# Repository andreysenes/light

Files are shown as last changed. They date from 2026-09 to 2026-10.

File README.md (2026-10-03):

# StageMod v0 — Iluminação de palco modular + MIDI

Repositório GitHub: [github.com/andreysenes/light](https://github.com/andreysenes/light) — ver [docs/GITHUB.md](docs/GITHUB.md) para `git push`.

**4 módulos** acopláveis (**8× WS2812B** cada, 32 pixels na cadeia) + **tubo 4 m** (200 LEDs), controlados pela **Medusa** (**Pro Micro** + **ZS-040** Bluetooth) ou **USB**, a partir de uma DAW.

## Arquitetura v0

```
DAW ──BT──► [ZS-040]──► [Pro Micro] ──D6──► Mod1 ──► Mod2 ──► Mod3 ──► Mod4
     └──USB (opc.)──────►      └── D5 ──► tubo neon 4 m
                               Fonte 5V 10A (C14 na Medusa)
```

| Peça | Função |
|---|---|
| **Medusa** | Pro Micro + **ZS-040** + fonte + XLR |
| **ZS-040** | MIDI sem fio (Bluetooth → Serial1) — [19-ZS-040.md](docs/19-ZS-040.md) |
| **Módulo spot** | 1× WS2812B + pass-through 5V/GND/DATA |
| **Tubo flex** | Fita WS2812B em tubo silicone — gradiente / chase (pin D5) |
| **Fonte 5V** | Pro Micro + spots + tubo (≥ **3A** com tubo) |

Cada WS2812B = **RGB completo** (milhões de cores via MIDI).

## Começar

| Passo | Onde |
|---|---|
| 1. Montar e soldar | [docs/22-MANUAL-MONTAGEM.md](docs/22-MANUAL-MONTAGEM.md) (sem caps/resistores) |
| 2. Upload firmware | [firmware/promicro-4mod/](firmware/promicro-4mod/) |
| 3. Mapear MIDI no DAW | [docs/05-MIDI-DAW.md](docs/05-MIDI-DAW.md) |
| 4. Controlar pelo browser | [andreysenes.github.io/light](https://andreysenes.github.io/light/) |

## Documentação v0

| Documento | Conteúdo |
|---|---|
| [Visão geral](docs/00-VISAO-GERAL.md) | Objetivos e decisões v0 |
| [Arquitetura](docs/01-ARQUITETURA-MODULAR.md) | Cabeça + 4 módulos em cadeia |
| [LEDs](docs/02-LEDS-E-OPTICA.md) | WS2812B RGB |
| [Eletrônica](docs/03-ELETRONICA.md) | Pro Micro, data, 5V |
| [Alimentação](docs/04-ALIMENTACAO.md) | Fonte 5V, limites |
| [MIDI / DAW](docs/05-MIDI-DAW.md) | CC RGB, notas, presets |
| [BOM](docs/06-BOM.md) | Lista de materiais v0 |
| [Cablagem](docs/07-CABLAGEM.md) | Fios por módulo |
| [XLR](docs/16-XLR-CONECTORES.md) | Pinagem 3 pinos — tubo + módulos |
| [**Cabeça Medusa**](docs/17-CABECA-MEDUSA.md) | Caixa Pro Micro + saídas XLR |
| [ZS-040](docs/19-ZS-040.md) | Bluetooth na Medusa |
| [MIDI sem fio](docs/18-WIRELESS-MIDI.md) | DAW, latência, bridge PC |
| [**Tubo flex**](docs/14-TUBO-FLEX.md) | Gradiente, chase, MIDI CC 15–19 |
| [**Compras AliExpress**](docs/15-ALIEXPRESS-BOM.md) | **O que buscar e o que evitar** |
| [Inventário hardware](docs/20-INVENTARIO-HARDWARE.md) | **O que já temos** |
| [**Lista de compras**](docs/21-LISTA-COMPRAS-RESTANTE.md) | **Itens restantes** |
| [**Manual de montagem**](docs/22-MANUAL-MONTAGEM.md) | Soldagem e ordem de montagem |
| [**Módulo spot 3D**](docs/23-MODULO-SPOT-3D.md) | STL + impressão + montagem mecânica |
| [Roadmap](docs/08-ROADMAP.md) | v0 atual → v1 futuro |
| [Resumo rápido](docs/DECISAO-RESUMO.md) | Decisões em 2 minutos |

## Decisões v0

| Tópico | Decisão |
|---|---|
| Cabeça | **1× Pro Micro** (ATmega32U4, MIDI USB) |
| Módulos | **4×** com **1 WS2812B** cada |
| Cor | **RGB completo** por módulo (CC 1–14) |
| Alimentação | **5 V** / ≥ 1 A |
| Dados spot | **D6** — cadeia 4 módulos |
| Tubo flex | **D5** — fita WS2812B (efeitos gradiente) |
| Cabos | 5V + GND + DATA (fios ou **XLR 3 pinos**) |

## MIDI rápido

| Módulo | R | G | B |
|---|---|---|---|
| 1 | CC 1 | CC 2 | CC 3 |
| 2 | CC 4 | CC 5 | CC 6 |
| 3 | CC 9 | CC 10 | CC 11 |
| 4 | CC 12 | CC 13 | CC 14 |

Notas **C3–F3** = módulos 1–4 (velocity = brilho). **CC 7** = dimmer. **PC 0** = blackout.

## v1 (futuro)

Rig de palco 24V, LEDs 10W, ESP32, P4 + RJ45 — especificação em [docs/v1/](docs/v1/).

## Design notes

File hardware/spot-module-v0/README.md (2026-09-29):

# Módulo spot StageMod v0 — impressão 3D

Coluna em **U** com **difusor frontal recuado** e **tampa inferior** para dois XLR (IN fêmea / OUT macho), alinhado ao visual de referência do projeto.

## Arquivos

| Arquivo | Descrição |
|---|---|
| `stagemod_spot_v0.scad` | Modelo paramétrico (OpenSCAD) |
| `stl/spot_body.stl` | Corpo (U + pés + calço LED) |
| `stl/spot_diffuser.stl` | Painel difusor |
| `stl/spot_bottom_plate.stl` | Tampa inferior (XLR) |
| `stl/spot_led_clip.stl` | Clipe opcional para fita |

Documentação de montagem elétrica: [docs/22-MANUAL-MONTAGEM.md](../../docs/22-MANUAL-MONTAGEM.md).  
Guia completo CAD: [docs/23-MODULO-SPOT-3D.md](../../docs/23-MODULO-SPOT-3D.md).

## Regenerar STL

```bash
./export-stl.sh
```

Requer [OpenSCAD](https://openscad.org/) 2021+.

## Ajuste rápido

No topo de `stagemod_spot_v0.scad`:

- `led_pitch` / `led_count` — deve bater com o seu PCB de 8× WS2812B  
- `xlr_hole_d` — medir o furo do conector XLR painel que você comprou  
- `outer_w`, `total_h` — escala estética

## Impressão sugerida

| Peça | Material | Notas |
|---|---|---|
| Corpo + tampa | PETG ou ABS | 0,2 mm, 3 perímetros, 20% infill |
| Difusor | PETG branco natural ou PLA branco | 0,12–0,2 mm; 2–4 perímetros; **100% infill** ou 4–6 paredes para difundir |
| Clipe | PETG | Opcional |

Orientação: corpo **deitado** (frente para cima ou costas na mesa) para boa resistência dos pés.

## Montagem (resumo)

1. Soldar LEDs e XLR conforme manual (sem caps/resistores).  
2. Encaixar PCB no calço interno; fios pela canaleta até a tampa.  
3. Parafusar XLR na `bottom_plate`; parafusar tampa no corpo (M3 × 10).  
4. Encaixar difusor na frente; 4× M3 × 8 (laterais do painel, opcional os da coluna lateral).  
5. Etiquetar **MOD 1…4**.

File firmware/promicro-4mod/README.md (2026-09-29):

# StageMod v0 — Firmware Pro Micro + 4× WS2812B

Firmware oficial da **v0**: **1 Pro Micro** e **4 LEDs WS2812B** (um por módulo), **RGB completo** via MIDI.

Documentação: [docs/](../../docs/) · MIDI: [05-MIDI-DAW.md](../../docs/05-MIDI-DAW.md) · Cablagem: [07-CABLAGEM.md](../../docs/07-CABLAGEM.md) · Cabeça: [17-CABECA-MEDUSA.md](../../docs/17-CABECA-MEDUSA.md)

## O que este firmware faz

- **MIDI USB** (cabeça perto do PC) + **Serial1** ← **ZS-040** (palco) — [18-WIRELESS-MIDI.md](../../docs/18-WIRELESS-MIDI.md)
- **4 módulos lógicos** = **32 pixels** (8 WS2812B por módulo físico, mesma cor por CC)
- **RGB completo** em cada módulo — qualquer cor via CC
- **Tubo flexível** (pin D5) — gradiente, chase, rainbow ([14-TUBO-FLEX.md](../../docs/14-TUBO-FLEX.md))
- Notas **C3–F3** acendem o módulo com a cor RGB já definida; **velocity** = brilho
- **PC 0–6** = presets de cor (blackout, warm, R, G, B, magenta, branco)
- **CC 7** = master dimmer

## Ligação elétrica

### Visão geral

```
[Fonte 5V] ──┬── VCC Pro Micro
             ├── VCC Mód 1 ── VCC Mód 2 ── VCC Mód 3 ── VCC Mód 4
             └── GND comum (Pro Micro + todos os módulos)

Pro Micro D6 ──► [470Ω] ──► DIN Mód1 ── ... ──► Mód4
Pro Micro D5 ──► [470Ω] ──► DIN fita WS2812B no tubo flexível
```

### Por módulo (chicote simples)

| Fio | IN | No módulo | OUT |
|-----|-----|---|-----|
| Vermelho | 5V | → LED VCC | 5V pass-through |
| Preto | GND | → LED GND | GND pass-through |
| Branco/verde | DATA | → LED DIN | LED DOUT → próximo |

Cada módulo é só **1 WS2812B** + 3 fios de pass-through (energia) + data série.

### Pro Micro (5V, 16MHz)

| Pro Micro | Liga em |
|---|---|
| **VCC** | 5V da fonte (ou USB só para programar — **não** alimentar 4 LEDs só no USB) |
| **GND** | GND comum |
| **D6** (ou `LED_PIN` no .ino) | Resistor 470Ω → DIN do módulo 1 |
| **RAW** | Opcional: 5V da fonte se não usar VCC |

### Boas práticas WS2812B

- **Cada módulo:** resistor **470 Ω** (DATA IN → DIN) + cap **470–1000 µF** (5V/GND no LED)
- **Medusa:** **470 Ω** em D5/D6 antes do XLR + **1000 µF** no barramento 5 V
- Fonte **5V / mín. 1 A** (4 LEDs × ~60 mA ≈ 240 mA no pior caso; use 1–2 A)
- Cabo de dados curto no protótipo (< 30 cm entre módulos)

## Arduino IDE — instalação

1. Placa: **Arduino Leonardo** ou **SparkFun Pro Micro** (5V, 16MHz)
2. Bibliotecas:
   - `MIDI Library` (FortySevenEffects)
   - `FastLED`
3. Abrir `promicro-4mod.ino` → Upload
4. No DAW: habilitar dispositivo MIDI USB do Pro Micro

### Pro Micro — pinagem comum

| Função | Pin |
|---|-----|
| LED data (padrão) | **6** |
| Alternativa | 5, 7, 8, 9… (alterar `LED_PIN`) |

## Mapa MIDI — RGB por módulo

Cada módulo tem **3 CCs** (R, G, B). Valor 0–127 no DAW → 0–255 no LED.

| Módulo | Vermelho | Verde | Azul |
|---|---|---|---|
| **1** | CC **1** | CC **2** | CC **3** |
| **2** | CC **4** | CC **5** | CC **6** |
| **3** | CC **9** | CC **10** | CC **11** |
| **4** | CC **12** | CC **13** | CC **14** |

| Entrada | Ação |
|---|---|
| **CC 1–14** | Define cor RGB do módulo (efeito imediato) |
| Nota **60–63** (C3–F3) | Módulo 1–4 — acende com cor dos CCs; velocity = brilho |
| Nota off | Apaga o módulo |
| **CC 7** | Master dimmer (todos) |
| **PC 0** | Blackout |
| **PC 1** | Warm white (todos) |
| **PC 2** | Vermelho |
| **PC 3** | Verde |
| **PC 4** | Azul |
| **PC 5** | Magenta |
| **PC 6** | Branco |

### Exemplo no DAW

1. Enviar **CC 1 = 127, CC 2 = 0, CC 3 = 0** → módulo 1 fica vermelho.
2. **CC 2 = 127** → amarelo (R+G).
3. Nota **C3** com velocity 100 → módulo 1 com brilho ~80 %.

Qualquer combinação R+G+B = **milhões de cores** — é a vantagem do WS2812B.

## Teste sem DAW

Após upload, o boot pisca os 4 módulos em branco em sequência. Se não piscar:

1. Verificar ordem GRB no `COLOR_ORDER` (alguns clones usam RGB)
2. Trocar `LED_PIN`
3. Medir 5V no LED

## Próximo passo (firmware)

- [x] RGB completo por módulo (CC 1–14)
- [ ] Migrar Cabeça para ESP32-S3 + RS-485 (doc principal do repo)
- [ ] Trocar WS2812B por LEDs 10W quando hardware estiver pronto

## v1 (futuro)

Rig 24V / 10W / ESP32 — [docs/v1/](../../docs/v1/README.md). A v0 valida **MIDI → luz modular** antes dessa migração.

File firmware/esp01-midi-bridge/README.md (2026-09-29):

# ESP-01 — bridge MIDI UDP → serial (opcional)

**Não faz parte da Medusa v0** — a cabeça usa **ZS-040** ([19-ZS-040.md](../../docs/19-ZS-040.md)). Este sketch é alternativa Wi‑Fi para quem não usar Bluetooth.

## Hardware

| ESP-01 | Ligação |
|---|---|
| VCC | **3,3 V** (regulador na Medusa) |
| GND | GND comum |
| TX | Pro Micro **RX (D0 / Serial1)** |
| RX | Pro Micro **TX (D1)** via divisor 5V→3,3 V |

**CH_PD** (EN) no ESP-01: ligar a **3,3 V** para manter o chip ativo.

## Upload

1. Adaptador USB **3,3 V** para ESP-01 (GPIO0 → GND no flash).
2. Arduino IDE: placa **Generic ESP8266 Module**, 1 MB flash.
3. Editar `WIFI_SSID` / `WIFI_PASS` no `.ino`.
4. Upload; anotar IP (Serial Monitor após boot ou roteador).

## Protocolo

- **UDP** porta **5004**
- Payload = bytes MIDI (ex. `0xB0 0x01 0x7F` = CC1 no canal 1)
- Sem cabeçalho extra — repasse direto para UART

## PC

Ver script de exemplo em [docs/18-WIRELESS-MIDI.md](../../docs/18-WIRELESS-MIDI.md).

## Pro Micro

`ENABLE_SERIAL_MIDI 1` e `SERIAL_MIDI_BAUD 115200` em `promicro-4mod.ino`.

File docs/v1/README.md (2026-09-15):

# StageMod v1 — planejado (não implementado)

Especificação do rig de palco **futuro**: ESP32-S3, módulos **2× 10 W**, alimentação **24 V**, cabos **P4 + RJ45**, lentes **20 mm 90°**.

O projeto **atual** é a **v0** (Pro Micro + 4× WS2812B) — ver [README principal](../../README.md).

| Documento | Conteúdo |
|---|---|
| [Cablagem P4 + RJ45](09-CABLAGEM.md) | Energia e dados separados |
| [Módulo Dual 10W](10-MODULO-DUAL.md) | WW + vermelho, ATtiny |
| [Configuração módulos](11-CONFIGURACAO-MODULOS.md) | `modules.json`, combinações de cor |
| [Lente 20 mm](12-LENTE-20MM.md) | Óptica 90° |
| [modules.json.example](modules.json.example) | Config v1 |

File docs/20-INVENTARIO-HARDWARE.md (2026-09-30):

# Inventário — hardware em mãos (Andrey)

Estado do rig **v0** com o que já está comprado/montado.

## Já temos

| Item | Especificação | Firmware / notas |
|---|---|---|
| **Pro Micro** | 5 V, ATmega32U4 | Cabeça Medusa |
| **ZS-040** | BLE → Serial1 | [19-ZS-040.md](19-ZS-040.md) |
| **Fonte** | **5 V 10 A** | Dentro da Medusa + **C14** |
| **Módulos spot** | **4×** WS2812B, **8 LEDs** cada | **32 pixels** na cadeia D6 — MIDI ainda **4 módulos** lógicos (CC 1–14) |
| **Tubo** | **4 m** × **50 LED/m** = **200 LEDs** | D5, WS2811 — `NUM_TUBE_LEDS 200` |

### Cadeia de pixels (pin D6)

```
Medusa D6 ──► [Mod1: LED 0–7] ──► [Mod2: 8–15] ──► [Mod3: 16–23] ──► [Mod4: 24–31]
```

Cada módulo físico: **8 LEDs** em série internos; **DOUT** do módulo → **DIN** do próximo. No firmware, **um** CC RGB acende **os 8 LEDs** do módulo com a mesma cor.

### Tubo (pin D5)

| Campo | Valor |
|---|---|
| Comprimento | 4 m |
| Densidade | 50 LED/m |
| Total | **200** addressable |
| Chip | WS2811 (D15-Woven Magic) |

## Ainda falta

Lista de compras completa: **[21-LISTA-COMPRAS-RESTANTE.md](21-LISTA-COMPRAS-RESTANTE.md)**.

Resumo: caixa Medusa + **C14** + fusível + XLR (Medusa e módulos) + cabos + USB painel.  
**Montagem/soldagem:** [22-MANUAL-MONTAGEM.md](22-MANUAL-MONTAGEM.md).

## Corrente (referência)

| Carga | Nominal / pico |
|---|---|
| 32 LEDs módulos (branco full) | ~**2 A** |
| Tubo 200 LED (manual 3,1 W/m) | ~**2,5 A** nominal |
| Pro Micro + ZS-040 | ~**0,15 A** |
| **Fonte 10 A** | Folga para efeitos e pico no tubo |

Injeção **5 V** no **meio** do tubo 4 m continua recomendada.

## Checklist primeiro power-on

1. [ ] `LEDS_PER_MODULE 8` e `NUM_TUBE_LEDS 200` no `.ino` (já padrão no repo)
2. [ ] Ligação 5V/GND/DATA conforme [22-MANUAL-MONTAGEM.md](22-MANUAL-MONTAGEM.md)
3. [ ] Ordem cadeia: Mod1 (C3) → Mod2 → Mod3 → Mod4 (F3)
4. [ ] Boot: cada módulo pisca **8 LEDs** juntos R/G/B/W; depois teste tubo
5. [ ] ZS-040 @ 115200 ou USB para MIDI

## Referências

- [07-CABLAGEM.md](07-CABLAGEM.md)
- [17-CABECA-MEDUSA.md](17-CABECA-MEDUSA.md)
- [firmware/promicro-4mod/](../firmware/promicro-4mod/)

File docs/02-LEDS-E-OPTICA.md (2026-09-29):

# LEDs — WS2812B RGB (v0)

## LED usado

| Item | Especificação |
|---|---|
| Tipo | **WS2812B** (ou WS2812B-B breakout) |
| Tensão | **5 V** |
| Cor | **RGB completo** — 8 bits por canal |
| Por módulo físico | **8× WS2812B** (mesma cor via MIDI) |
| Módulos lógicos (MIDI) | **4** |
| Total cadeia D6 | **32 pixels** |
| Tubo D5 | **200** LEDs (4 m × 50/m) |

## Por que WS2812B na v0

| Vantagem | Detalhe |
|---|---|
| RGB completo | Milhões de cores — sem misturar LEDs mono |
| 1 fio data | Cadeia simples entre módulos |
| Barato | Comum em estoque DIY |
| Integrado | Driver dentro do LED — sem MOSFET |

## Cor e brilho

| Controle MIDI | Efeito |
|---|---|
| CC 1–14 | R, G, B por módulo (0–255) |
| CC 7 | Master dimmer (FastLED brightness) |
| Velocity (notas) | Escala RGB do módulo |
| PC presets | Cores pré-definidas em todos |

Não é necessário LED warm white separado — **R+G parcial** faz amarelo/laranja; **R+G+B** faz branco.

## Consumo

| Estado | Corrente por LED | 4 LEDs |
|---|---|---|
| Apagado | ~1 mA | ~4 mA |
| Cor média | ~20–40 mA | ~80–160 mA |
| Branco full | ~60 mA | **~2 A** (32 LEDs) + tubo à parte |

Fonte **5V / 1A** é suficiente com margem.

## Ordem de cores no firmware

```cpp
#define COLOR_ORDER GRB   // padrão WS2812B
```

Se as cores saírem trocadas (vermelho aparece verde), testar `RGB` ou `BGR` no `.ino`.

## Limitações vs. palco grande

| WS2812B v0 | LED 10W v1 (futuro) |
|---|---|
| ~0,3 W / LED | ~10–20 W / módulo |
| Luz de proximidade / efeito | Wash de palco |
| Sem lente dedicada | Lente 20mm 90° planejada |

Para wash de palco grande, evoluir para [v1](v1/README.md).

## Boot visual

Após upload, firmware pisca cada módulo: **vermelho → verde → azul → branco** — confirma ordem da cadeia e ordem GRB.

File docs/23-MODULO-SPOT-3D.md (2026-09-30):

# Módulo spot — design 3D (impressão + montagem)

Corpo inspirado na **coluna vertical** de referência: perfil em **U**, **difusor branco recuado** na frente, **pés** nas laterais e **parafusos aparentes** (M3) na lateral e na base do difusor.

| Item | Valor padrão (CAD) |
|---|---|
| Altura total | **300 mm** |
| Largura frontal | **48 mm** |
| Profundidade | **34 mm** |
| LEDs | **8× WS2812B** em coluna (pitch **10 mm** ajustável no `.scad`) |
| Conectores | **2× XLR** na tampa inferior (IN ≈ 25% largura, OUT ≈ 75%) |

Arquivos: [`hardware/spot-module-v0/`](../hardware/spot-module-v0/).

---

## Peças impressas (×4 módulos)

| STL | Qtd/módulo | Função |
|-----|---|---|
| `spot_body.stl` | 1 | Carcaça U + pés + calço para PCB |
| `spot_diffuser.stl` | 1 | Painel difusor frontal |
| `spot_bottom_plate.stl` | 1 | Base com furos XLR |
| `spot_led_clip.stl` | 0–2 | Opcional se a fita não encaixar no calço |

Hardware de montagem (por módulo, típico):

| Item | Qtd |
|---|-----|
| Parafuso M3 × 10 | 4 (tampa) + 2–4 (difusor) |
| Porca M3 ou insert térmico M3 | conforme furo |
| XLR fêmea painel (IN) | 1 |
| XLR macho painel (OUT) | 1 |

---

## Fluxo de montagem mecânica

```
1. Imprimir corpo + difusor + tampa
2. Soldar 8 LEDs + fios nos XLR (ver manual elétrico)
3. Parafusar XLR na tampa inferior; passar cabos pelo furo central
4. Fixar tampa no corpo (M3 nos 4 cantos)
5. Encaixar PCB no calço traseiro; fios pela canaleta
6. Deslizar difusor no slot frontal; parafusar na base (e opcionalmente lateral)
7. Etiqueta MOD 1…4 na parte de trás
```

Ordem elétrica e testes: [22-MANUAL-MONTAGEM.md](22-MANUAL-MONTAGEM.md) — Parte 3 (cabos) e Parte 5 (firmware).

---

## Ajustar ao seu LED

Abra `hardware/spot-module-v0/stagemod_spot_v0.scad` e altere:

| Variável | Quando mudar |
|---|---|
| `led_pitch` | Fita 60 LED/m → ~16,7 mm; 100 LED/m → ~10 mm |
| `led_pcb_w` | Largura do breakout (muitos usam 10 mm) |
| `led_count` | Manter **8** no StageMod v0 |
| `xlr_hole_d` | Medir o recorte do conector (muitos painéis ≈ 22–24 mm) |

Depois rode `./export-stl.sh` e reimprima só a peça afetada (geralmente corpo ou difusor).

---

## Impressão 3D

| Parâmetro | Corpo / tampa | Difusor |
|---|---|---|
| Material | PETG (palco) ou PLA (prototipo) | PETG branco / PLA branco |
| Camada | 0,2 mm | 0,12–0,2 mm |
| Infill | 15–25% | 100% ou 6+ paredes |
| Suportes | Só se inclinar; preferir corpo **costas na mesa** | Não |
| Pós-processo | Lixar encaixe do difusor se apertado | Lixar faces internas para mais difusão |

**Difusor:** se a luz mostrar “pontos” dos LEDs, use filme difusor adesivo por dentro ou aumente a espessura (`diffuser_thick` no SCAD).

---

## Vista explodida (conceito)

```
        ┌─────────────┐
        │  difusor    │  ← recuado ~4,5 mm
        ├─────────────┤
        │ 8× LED      │  ← calço traseiro
        │   coluna    │
        │  (U-body)   │
        └──────┬──────┘
          pés  │  pés
        ┌──────┴──────┐
        │ bottom_plate│  ← XLR IN | XLR OUT
        └─────────────┘
```

---

## Referência visual

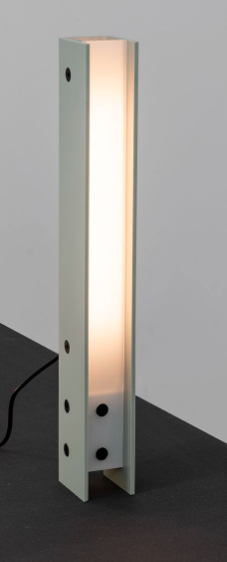
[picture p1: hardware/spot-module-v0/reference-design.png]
Referência de design


A geometria segue esta coluna (U + difusor recuado + pés). Fotos da sua montagem podem ir em `hardware/spot-module-v0/photos/`.

---

## Próximos passos (opcional)

- Versão com **encaixe magnético** na tampa para manutenção  
- **STEP** exportado do OpenSCAD para edição no FreeCAD  
- Variante **mais baixa** (~220 mm) para transporte

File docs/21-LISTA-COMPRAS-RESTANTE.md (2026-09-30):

# Lista de compras — itens restantes

**Já em mãos (não comprar de novo):** Pro Micro, ZS-040, fonte 5 V 10 A, 4 módulos WS2812B (8 LEDs cada), tubo 4 m (200 LED).

---

## Obrigatório — Medusa (cabeça)

| # | Qty | Item | Busca AliExpress / loja |
|---|-----|---|---|
| 1 | 1 | Caixa ABS grande | `ABS project box 150x100` (cabe C14 + fonte + placas) |
| 2 | 1 | **C14** painel IEC | `IEC320 C14 power inlet panel mount` |
| 3 | 1 | Cabo **C13** → tomada | `C13 power cord` (ou reaproveitar de PC) |
| 4 | 1 | Suporte fusível **5×20 mm** | `fuse holder 5x20mm panel` |
| 5 | 1 | Fusível **2 A** retardado | `5x20 fuse 2A slow blow` |
| 6 | 2 | XLR **fêmea** painel | `XLR female 3 pin panel mount` — **MOD** + **TUBO** |
| 7 | 1 | USB **micro** painel | `micro USB panel mount socket` |
| 8 | 0–1 | Par **1 kΩ + 2 kΩ** | Só se ZS-040 exigir divisor 3,3 V no RX |
| 9 | — | Fio **AWG 18** verm./preto | Barramento 5 V / GND na caixa |
| 10 | — | Fio **AWG 22** verde/branco | D5, D6 → XLR |

## Obrigatório — cada módulo spot (×4)

| # | Qty total | Item | Onde |
|---|---|---|---|
| 11 | **4** | XLR **fêmea** painel (IN) | Entrada do módulo |
| 12 | **4** | XLR **macho** painel (OUT) | Saída para o próximo módulo |

Montagem: [22-MANUAL-MONTAGEM.md](22-MANUAL-MONTAGEM.md) (ligação direta DATA/5V/GND).

## Cabos palco (tentáculos)

| # | Qty | Item | Notas |
|---|-----|---|---|
| 13 | 1 | Cabo XLR **Medusa → Mod1** | 1–2 m, 3 condutores + malha GND |
| 14 | 1 | Cabo XLR **Medusa → tubo** | 3–5 m |
| 15 | 3 | Cabo XLR **Mod → Mod** | 0,3–1 m (ou montar com `microphone cable`) |
| 16 | 0–1 | Cabo só **5 V/GND** (opc.) | Injeção no **meio** do tubo 4 m |

Montar cabo: `microphone cable 2 core shield` — vermelho=5 V, preto=GND, verde=DATA, malha=GND.

## Opcional (recomendado)

| # | Item | Motivo |
|---|---|---|
| 17 | XLR fêmea extra (**INJ**) | Só 5 V/GND para reforço no tubo |
| 18 | **AMS1117-3.3** | Só se o ZS-040 **não** aceitar 5 V no VCC |
| 19 | Chave **rocker** na entrada AC | Desligar rig sem puxar C13 |
| 20 | Terminais **spade** / olhal | C14 → fios da fonte (mais seguro que solda solta) |
| 21 | Espaçador **M3** + parafusos | Fixar Pro Micro e fonte na caixa |

---

## Checklist rápido antes de pedir

- [ ] **8×** XLR painel nos módulos (4 IN + 4 OUT) + **2×** na Medusa (MOD, TUBO)
- [ ] Caixa + C14 + fusível + USB painel
- [ ] Cabos ou material para **5** cabos XLR

## Estimativa de custo (referência)

| Grupo | ~US$ |
|---|---|
| Caixa + C14 + fusível + USB | 15–25 |
| XLR painel (10 peças) | 10–20 |
| Resistores + caps + fios | 5–10 |
| Cabos prontos (ou DIY) | 15–40 |
| **Total** | **~45–95** |

Envio Brasil: variável (Choice / Standard).

## Referências

- Montagem: [17-CABECA-MEDUSA.md](17-CABECA-MEDUSA.md)
- Inventário: [20-INVENTARIO-HARDWARE.md](20-INVENTARIO-HARDWARE.md)
- AliExpress detalhado: [15-ALIEXPRESS-BOM.md](15-ALIEXPRESS-BOM.md)

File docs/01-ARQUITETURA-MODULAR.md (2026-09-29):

# Arquitetura — v0

## Papéis

| Peça | MCU? | Função |
|---|---|---|
| **Cabeça** | Pro Micro + **ZS-040** | MIDI USB ou BT → pixels WS2812B |
| **Módulo 1–4** | Nenhum | **8× WS2812B** (1 cor MIDI) + pass-through cabos |
| **Tubo flex** | Nenhum | Fita WS2812B em tubo silicone (muitos pixels) |
| **Fonte 5V** | — | Alimentação (10A com tubo 4m) |
| **ZS-040** | BLE UART | MIDI sem fio → Serial1 — [19-ZS-040.md](19-ZS-040.md) |

Não há ESP32, RS-485 nem decoder nos módulos na v0.

## Fluxo de dados

```mermaid
flowchart LR
    DAW[DAW] -->|USB ou BT| PM[Pro Micro]
    DAW -.->|BLE| ZS[ZS-040]
    ZS -->|Serial1| PM
    PM -->|D6| M1[Módulo 1]
    M1 --> M2 --> M3 --> M4
    PM -->|D5| TUB[Tubo flex WS2812B]
```

- Cadeia D6: **32 pixels** (módulos 0–7, 8–15, 16–23, 24–31)
- MIDI: **4 módulos lógicos** — cada CC RGB pinta **8 LEDs** iguais

## Cabeça (Pro Micro)

| Item | Especificação |
|---|---|
| Placa | SparkFun Pro Micro 5V / Arduino Leonardo |
| USB | MIDI nativo (ATmega32U4) |
| Data módulos | **Pin 6** (`MODULE_PIN`) |
| Data tubo | **Pin 5** (`TUBE_PIN`) |
| Firmware | `firmware/promicro-4mod/promicro-4mod.ino` |

### Responsabilidades

1. Receber MIDI (CC, notas, Program Change)
2. Manter cor RGB de cada módulo
3. Atualizar cadeia WS2812B (`FastLED.show()`)

## Módulo (repetível × 4)

```
     IN                          OUT
  5V ──┬── VCC LED ──┬── 5V
 GND ──┴── GND LED ──┴── GND
DATA ───── DIN    DOUT ─── DATA
```

| LED na cadeia | Índice firmware | Nota MIDI |
|---|---|---|
| Módulo 1 (primeiro) | 0 | C3 (60) |
| Módulo 2 | 1 | D3 (61) |
| Módulo 3 | 2 | E3 (62) |
| Módulo 4 (último) | 3 | F3 (63) |

## Alimentação

- **5V** e **GND** em paralelo em todos os módulos (não passam pelo Pro Micro para os LEDs)
- Pro Micro: VCC da mesma fonte 5V ou USB só para programar

## Expansão

| Mudança | Esforço |
|---|---|
| Mais de 4 módulos | Alterar `NUM_MODULES` + fonte maior |
| Módulos físicos separados | Mesma cadeia DATA |
| v1 (24V, 10W) | Nova Cabeça + novos módulos — [v1/README.md](v1/README.md) |

## Topologia física

```
        [Mod1]──[Mod2]──[Mod3]──[Mod4]
           ▲
      [Cabeça Medusa: Pro Micro + XLR MOD/TUBO + fonte 5V]
```

Detalhes da caixa cabeça: [17-CABECA-MEDUSA.md](17-CABECA-MEDUSA.md).

Splits em T **não** aplicam na v0 — uma única cadeia DATA.

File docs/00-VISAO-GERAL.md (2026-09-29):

# Visão geral — StageMod v0

## Objetivo

Sistema de **4 módulos de luz** para palco/ensaio, controlados por **MIDI** a partir de uma DAW, usando componentes acessíveis:

- **Medusa**: **Pro Micro** + **ZS-040** (Bluetooth MIDI) + fonte **5V** na caixa
- **WS2812B** (RGB completo) em cada módulo
- **USB** opcional quando a cabeça está perto do PC

## O que é v0

| Inclui | Não inclui (v1) |
|---|---|
| 4 módulos, 1 LED RGB cada | LEDs 10W mono |
| MIDI USB + **ZS-040** (BT) | RS-485 / P4 / RJ45 |
| Pro Micro + ZS-040 | ESP32 |
| Cadeia WS2812B (1 fio data) | ATtiny nos módulos |
| Fonte 5V | Fonte 24V |

## Diagrama

```
┌─────────────┐   5V + GND + DATA    ┌──────────────────┐
│ Pro Micro   │ ───────────────────► │ Módulo 1         │
│ MIDI USB    │                      │ 1× WS2812B RGB   │
└─────────────┘                      └────────┬─────────┘
                                              │ DOUT
                                              ▼
                                     Mod2 ──► Mod3 ──► Mod4
```

## Módulo físico

Cada módulo é mínimo:

- **1× WS2812B** (breakout ou LED em star)
- **IN / OUT**: 5V, GND, DATA (pass-through)

Não há MCU no módulo — só o LED e fios.

## Controle de cor

O WS2812B permite **qualquer cor RGB**:

- **CC 1–14** no DAW → R, G, B de cada módulo
- **Notas C3–F3** → acendem módulo com cor definida; velocity = brilho
- **PC 0–6** → presets (blackout, warm, R, G, B, magenta, branco)

Detalhes: [05-MIDI-DAW.md](05-MIDI-DAW.md).

## Limites v0

| Fator | Valor |
|---|---|
| Módulos | **4** (fixo no firmware) |
| Corrente total | ~250 mA (4 LEDs full white) |
| Distância DATA | < 1 m entre módulos (ideal) |
| Tensão | **5 V apenas** |

## Evolução para v1

Quando o protótipo MIDI estiver validado, migrar para rig 24V / 10W / ESP32 — ver [v1/README.md](v1/README.md).

## Glossário

| Termo | Significado |
|---|---|
| Cabeça | Pro Micro — único MCU |
| Módulo | 1 WS2812B + pass-through |
| Cadeia WS2812 | LEDs em série no mesmo fio DATA |
| DIN / DOUT | Entrada / saída de dados do LED |

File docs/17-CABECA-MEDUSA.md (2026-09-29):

# Cabeça Medusa — Pro Micro + ZS-040

A **Medusa** é a caixa da cabeça do StageMod. Dentro da caixa há **apenas**:

| Peça | Função |
|---|---|
| **Pro Micro** | Pixels (D5/D6), MIDI **USB** e **Serial1** (ZS-040) |
| **ZS-040** | Bluetooth → UART → Pro Micro |
| **Entrada C14** + **fonte 5 V 10 A** (dentro da caixa) | Rede → DC para o rig |
| **Passivos / XLR** | Barramento 5 V, saídas módulos e tubo |

Não há ESP-01 nem segundo MCU — só **Pro Micro + ZS-040**.

## Dois modos de MIDI (sem trocar firmware)

| Modo | Conexão | Quando |
|---|---|---|
| **Sem fio** | DAW → BT → ZS-040 → Serial1 | Palco, cabeça longe do PC |
| **USB** | DAW → USB → Pro Micro | Cabeça perto do notebook; menor latência |

Ambos podem ficar **habilitados** no firmware; na DAW use **só um** caminho por vez.

Hardware ZS-040: [19-ZS-040.md](19-ZS-040.md) · DAW e latência: [18-WIRELESS-MIDI.md](18-WIRELESS-MIDI.md).

## Função

| Entrada | Saídas |
|---|---|
| **C14** (cabo C13 “panela”) → SMPS **5 V 10 A** interna | **MOD** — D6 + 5V + GND |
| — | **TUBO** — D5 + 5V + GND |
| — | **INJ** (opc.) — só 5V + GND |
| **DAW** (Bluetooth) | ZS-040 → Serial1 |
| **USB micro** | Pro Micro — programação + MIDI com cabo |

Pinagem XLR: [16-XLR-CONECTORES.md](16-XLR-CONECTORES.md).

## Vista geral

```
[Cabo C13 rede]──► C14 ──► [SMPS 5V 10A dentro da caixa]
                    ┌─────────────────────────────────────┐
                    │  +5V / GND barramento                 │
                    │  ┌──────────┐    ┌─────────┐        │
   [DAW BT]─────────│  │ ZS-040   │UART│Pro Micro│◄──USB (opc.)
                    │  │ (5V*)    ├───►│ Serial1 │        │
                    │  └──────────┘    └────┬────┘        │
                    │    D6 ──[470Ω]──► XLR MOD           ├──► Mod1…
                    │    D5 ──[470Ω]──► XLR TUBO          ├──► tubo
                    │    5V/GND ───────► XLR INJ          │
                    └─────────────────────────────────────┘
                    * VCC 5V se o breakout permitir; senão 3,3 V
```

```mermaid
flowchart TB
  MAINS[Rede C13/C14]
  PSU[SMPS 5V 10A interna]
  MEDUSA[Cabeça Medusa]
  BT[ZS-040 BLE]
  PM[Pro Micro]
  DAW[DAW]
  USB[USB opcional]

  MAINS --> MEDUSA
  PSU --> MEDUSA
  DAW -->|Bluetooth| BT
  BT -->|Serial1| PM
  DAW -.->|USB quando perto| PM
  PM --> MEDUSA
  MEDUSA -->|XLR MOD| CHAIN[Mod1 → Mod4]
  MEDUSA -->|XLR TUBO| TUBE[Tubo 4 m]
```

## Painel

```
┌──────────────────────────────────────────┐
│  [C14]   STAGEMOD v0      [USB micro]    │  ← C14 = entrada rede (cabo C13)
│   (MOD)  (TUBO)  (INJ)                   │
│     ○      ○       ○                     │
└──────────────────────────────────────────┘
```

Furo painel **C14** (IEC 60320): retângulo padrão do conector + 2 parafusos nas orelhas.

## Entrada de rede — conector C14

| Item | Especificação |
|---|---|
| Conector painel | **IEC C14** (receptáculo; cabo **C13** na parede) |
| Fonte interna | SMPS **100–240 V AC** → **5 V DC 10 A** (a mesma da BOM) |
| Cabo externo | **C13** macho ↔ tomada (Brasil: 127/220 V conforme rede) |

### Ligação C14 → fonte (lado AC)

Vista **traseira** do C14 (terminals em spade):

| Terminal C14 | Função | → SMPS AC |
|---|---|---|
| **Terra** (geralmente **centro** / símbolo ⏚) | PE | **FG / ⏚** da fonte |
| **Fase** | L | **L** (após **fusível** em série, ex. **2 A** retardado) |
| **Neutro** | N | **N** |

Use fio **AWG 18** (ou 1,0 mm²) para AC; **termoretrátil** e **cannotilho**; nenhum condutor exposto na tampa.

**Aviso:** trabalho em **tensão de rede** — desligar na tomada, testar com multímetro e, se não tiver experiência, pedir ajuda a eletricista. A carcaça da caixa **metálica** deve ligar ao **PE** do C14.

### Saída DC (5 V) → barramento

| SMPS DC | Medusa |
|---|---|
| **+V** | Barramento 5 V → Pro Micro, ZS-040, pinos 2 dos XLR |
| **−V** | GND comum → Pro Micro, shells XLR, INJ |

```
   [C14] ── L/N/PE ──► [Fusível] ──► SMPS 100-240V
                              │
                         +5V / GND ──┬── Pro Micro
                                      ├── ZS-040
                                      ├── [1000µF]
                                      └── XLR MOD/TUBO/INJ (pinos 1-2)
```

## Esquema elétrico interno (baixa tensão)

```
        +5V ──┬──► VCC Pro Micro
              ├──► VCC ZS-040 (5V ou 3V3 via AMS1117)
              ├──► XLR pin 2 (MOD, TUBO, INJ)
              └── [1000µF] ── GND

        GND ──┴── shells XLR, Pro Micro, SMPS −V

        ZS TX ───────────────► Pro Micro RX (D0 / Serial1)
        Pro Micro TX (D1) ───► ZS RX  (divisor se 3V3)

        D6/D5 ──[470Ω]──► XLR MOD / TUBO pin 3
```

## BOM da Medusa

| Qty | Item | Notas |
|-----|---|---|
| 1 | Pro Micro 5V 32U4 | Já tem |
| 1 | **ZS-040** (BLE UART) | Breakout com **entrada 5 V** de preferência |
| 0–1 | AMS1117-3.3 | Só se o seu ZS-040 for **3,3 V** estrito |
| 1 | **C14** painel (IEC 60320) | Entrada rede + cabo C13 |
| 1 | SMPS **5 V 10 A** 100–240 V | **Dentro** da Medusa |
| 1 | Fusível **2 A** + suporte | Série na fase (L) |
| 1 | Cabo C13 1,5 m (ou usar existente) | Tomada → Medusa |
| 1 | Caixa ABS grande | C14 + SMPS + USB + XLR |
| 2–3 | XLR fêmea painel | MOD, TUBO, INJ |
| 2 | 470 Ω | Saídas **D5** e **D6** → XLR (além do 470 Ω **em cada módulo**) |
| 1 | 1000 µF 16 V | Barramento 5 V na Medusa (além do cap **em cada módulo**) |
| 1 | USB micro painel | Pro Micro |
| — | Divisor 1k/2k | TX Pro Micro → RX ZS (se necessário) |

## Firmware

| Peça | Onde |
|---|---|
| Pro Micro | `promicro-4mod.ino` — `ENABLE_USB_MIDI 1`, `ENABLE_SERIAL_MIDI 1` |
| ZS-040 | Transparente; configurar **AT+BAUD4** (115200) uma vez |

## Ordem de montagem

1. ZS-040 em adaptador USB: testar `AT`, subir baud, parear no PC.
2. Soldar UART ao Pro Micro; upload firmware.
3. **C14 + SMPS** (AC só com caixa fechada após teste de isolamento); barramento 5 V + XLR.
4. Teste MOD com **BT** e depois com **USB**.

## Referências

- [18-WIRELESS-MIDI.md](18-WIRELESS-MIDI.md)
- [16-XLR-CONECTORES.md](16-XLR-CONECTORES.md)
- [07-CABLAGEM.md](07-CABLAGEM.md)

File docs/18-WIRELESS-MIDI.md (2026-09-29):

# MIDI sem fio — Medusa (ZS-040 + Pro Micro)

Hardware e pinagem do **ZS-040**: **[19-ZS-040.md](19-ZS-040.md)**.

Na **Medusa** o rádio é o **ZS-040** (BLE UART). O **Pro Micro** aceita **dois caminhos ao mesmo tempo**:

| Modo | Quando | Latência típica |
|---|---|---|
| **USB** no Pro Micro | Cabeça **perto** do PC (ensaio, gravação) | ~1–3 ms |
| **ZS-040** (Bluetooth) | Cabeça **no palco**, sem cabo USB | ~15–40 ms |

Para **luz com música**, **15–40 ms** costuma ser aceitável: em **120 BPM**, uma semínima ≈ **125 ms** — o atraso do BT fica **abaixo de um 16º** perceptível na maioria das cenas. Hits muito secos no beat podem preferir **USB** naquele dia.

Firmware lê **USB e Serial1 em paralelo** — não precisa recompilar ao trocar; só **não envie MIDI duplicado** da DAW para as duas portas ao mesmo tempo.

## Arquitetura

```
                    ┌─ USB MIDI (opcional, cabo curto)
DAW ──► [PC] ───────┤
        │           │
        └── BT serial ──► ZS-040 ── UART ──► Pro Micro Serial1 ──► LEDs
                              ▲
                         VCC (5V breakout comum)
```

| Camada | Função |
|---|---|
| PC | Parear BT; porta **COM** serial; bridge **MIDI → serial** (Hairless, etc.) |
| ZS-040 | BLE transparente UART |
| Pro Micro | `MIDI.read()` (USB) + `MIDI_Serial.read()` (ZS) |

## Por que ZS-040 na Medusa

| Vantagem | Detalhe |
|---|---|
| **Alimentação simples** | Muitos breakouts **ZS-040/HM-10** aceitam **5 V** no VCC (regulador onboard) — mesmo barramento da Medusa, sem ESP + AMS1117 |
| **PC** | Bluetooth nativo no notebook — sem script UDP |
| **Montagem** | UART + 4 fios; sem firmware no módulo BT |

**Alternativa** (não usada na Medusa v0): [ESP-01 + UDP](../firmware/esp01-midi-bridge/) — menor latência, mais eletrônica.

## Ligação na Medusa

### Alimentação

| Módulo | Alimentação |
|---|---|
| Pro Micro | **5 V** do barramento |
| ZS-040 | **5 V** no breakout **se** o vendedor indicar 3,3–6 V / “5V tolerant”; senão **3,3 V** do mesmo 5 V via AMS1117 |

Confirme no seu módulo: pinos **VCC / GND / TX / RX** — não inverter.

### UART (Serial1)

| Pro Micro | ZS-040 |
|---|---|
| **RX (D0)** | **TX** do módulo |
| **TX (D1)** | **RX** do módulo (divisor 5 V→3,3 V se lógica 3,3 V) |
| **GND** | **GND** |

Se o breakout já nivelar TX para o Arduino, o divisor no RX do ZS-040 pode ser opcional.

### Painel

```
[USB micro]  ← Pro Micro: programação + MIDI com cabo
[MOD][TUBO][INJ]  ← XLR
ZS-040 dentro da caixa (antena para fora do metal)
```

## Configurar baud do ZS-040

Padrão de fábrica costuma ser **9600**. Recomendado subir para **115200** (menos atraso em fila serial).

1. Ligue o ZS-040 num adaptador USB-UART (3,3 V ou 5 V conforme o módulo).
2. Terminal serial **9600**, sem newline ou com `\r\n` conforme o clone.
3. Comandos AT (HM-10 / ZS-040 compatível):

```
AT
AT+BAUD4
```

`BAUD4` ≈ **115200** na tabela HM-10. Reinicie o módulo.

4. No `promicro-4mod.ino`:

```cpp
#define ENABLE_USB_MIDI     1
#define ENABLE_SERIAL_MIDI  1
#define SERIAL_MIDI_BAUD    115200   // ou 9600 se não alterou o AT
```

## PC — Bluetooth → MIDI

1. **Parear** o ZS-040 no sistema (nome tipo `HMSoft`, `BT04`, etc.).
2. Anotar a porta **COM** (Windows) ou `/dev/cu.*` (macOS).
3. Usar um bridge **MIDI ↔ serial** na mesma baud do módulo, por exemplo:
   - [Hairless MIDI](https://projectgus.github.io/hairless-midiserial/) (Win/mac/Linux)
   - Ou equivalente que envie bytes MIDI crus na COM

4. Na DAW: saída MIDI → porta virtual do bridge → **COM do ZS-040**.

Não use phantom power nem entrada de microfone — é **UART digital**.

## USB direto (cabeça perto)

1. Cabo **USB micro** no Pro Micro.
2. DAW: dispositivo MIDI **Arduino / Pro Micro** (nativo USB MIDI).
3. Pode **desligar** o bridge Bluetooth na DAW para evitar mensagens duplicadas.
4. Firmware: manter `ENABLE_USB_MIDI 1` (já é o padrão).

## Latência — expectativa honesta

| Caminho | Ordem de grandeza | Uso |
|---|---|-----|
| USB | 1–3 ms | Ensaio, cabeça ao lado do notebook |
| ZS-040 BLE | 15–40 ms | Show, rig longe do PC |
| Jitter BT | Ocasional pico | Evitar flood de CC; preferir mudanças de cor em blocos |

Iluminação de palco raramente precisa de sub-5 ms; **sincronizar com música** em BPM humanos costuma funcionar bem com BT se a DAW já compensa latência de áudio (não a de luz).

## Checklist

- [ ] ZS-040 pareado; COM abre sem erro
- [ ] Baud **igual** no AT, no bridge e em `SERIAL_MIDI_BAUD`
- [ ] `MIDI_CHANNEL` = canal da DAW (padrão **1**)
- [ ] Teste **CC1** antes do rig completo
- [ ] Com USB ligado: **uma** fonte MIDI ativa na DAW

## Referências

- [17-CABECA-MEDUSA.md](17-CABECA-MEDUSA.md)
- [05-MIDI-DAW.md](05-MIDI-DAW.md)
- Firmware Pro Micro: [promicro-4mod.ino](../firmware/promicro-4mod/promicro-4mod.ino)
- Alternativa Wi‑Fi: [esp01-midi-bridge](../firmware/esp01-midi-bridge/) (opcional)

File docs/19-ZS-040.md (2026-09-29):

# ZS-040 — Bluetooth MIDI (Medusa)

O **ZS-040** (clone **HM-10** / BLE UART) é o módulo de **conexão sem fio** oficial do StageMod v0, montado na [**Medusa**](17-CABECA-MEDUSA.md) junto do Pro Micro.

## Função no projeto

| Caminho | Hardware |
|---|---|
| **Palco** (sem cabo USB) | DAW → Bluetooth → **ZS-040** → **Serial1** → Pro Micro |
| **Ensaio** (cabeça perto) | DAW → **USB** → Pro Micro (mesmo firmware) |

Firmware: `ENABLE_SERIAL_MIDI 1` em [promicro-4mod.ino](../firmware/promicro-4mod/promicro-4mod.ino).

## Pinagem típica do módulo

Confirme no silk da sua placa (nomes variam):

| Pino ZS-040 | Ligação Medusa |
|---|---|
| **VCC** | **5 V** (se breakout permitir) ou **3,3 V** (AMS1117) |
| **GND** | GND comum |
| **TX** | Pro Micro **RX** — **D0** / **Serial1** |
| **RX** | Pro Micro **TX** — **D1** (divisor 5 V→3,3 V se necessário) |

```
Pro Micro (5V)                    ZS-040
    D0 RX ◄────────────────────── TX
    D1 TX ──[1k]──┬──────────────► RX
                  │
                 [2k]
                  │
                 GND
    5V ───────────────► VCC (ou 3V3)
    GND ──────────────► GND
```

## Configuração AT (uma vez)

Adaptador USB-UART, terminal **9600** 8N1, comandos terminados com `\r\n`:

| Comando | Função |
|---|---|
| `AT` | Responde `OK` |
| `AT+BAUD4` | UART **115200** (igual ao firmware) |
| `AT+NAMEStageMod` | Nome visível no Bluetooth (opcional) |
| `AT+ROLE0` | Periférico BLE (padrão em muitos clones) |

Depois do `AT+BAUD4`, ajuste o terminal e o [bridge no PC](18-WIRELESS-MIDI.md) para **115200**.

## No PC

1. Parear **ZS-040** (Bluetooth do sistema).
2. Abrir porta **COM** criada.
3. Bridge **MIDI → serial** (ex. Hairless MIDI Serial) @ **115200**.
4. DAW → porta MIDI virtual do bridge.

Não enviar MIDI **ao mesmo tempo** pela USB e pelo BT.

## Comprar

| Busca AliExpress | Notas |
|---|---|
| `ZS-040 bluetooth 4.0 serial` | |
| `HM-10 CC2541 module` | Compatível AT |

Preferir placa com **regulador** e entrada **5 V** marcada na descrição.

## Documentação relacionada

- [18-WIRELESS-MIDI.md](18-WIRELESS-MIDI.md) — latência, checklist, DAW
- [17-CABECA-MEDUSA.md](17-CABECA-MEDUSA.md) — montagem na caixa
- [05-MIDI-DAW.md](05-MIDI-DAW.md) — mapa CC/notas

## Alternativa (fora do BOM v0)

Wi‑Fi **ESP-01** + UDP: [firmware/esp01-midi-bridge/](../firmware/esp01-midi-bridge/) — não usado na Medusa atual.

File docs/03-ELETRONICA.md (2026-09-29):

# Eletrônica — v0

## Esquema geral

```
[Fonte 5V] ──┬── VCC Pro Micro
             ├── VCC ──► LED1 ──► LED2 ──► LED3 ──► LED4
             └── GND comum

Pro Micro D6 ──[470Ω]──► DIN LED1 ── DOUT ──► DIN LED2 ── ...
```

## Pro Micro (cabeça)

| Pino | Ligação |
|---|---|
| **VCC** | 5V (fonte externa recomendada com LEDs ligados) |
| **GND** | GND comum |
| **D6** | Resistor 470Ω → DIN primeiro WS2812B |
| **USB** | Programação + MIDI para DAW |

### Bibliotecas firmware

- **FastLED** — driver WS2812B
- **MIDI Library** (FortySevenEffects) — MIDI USB

## Por módulo

| Conexão | Destino |
|---|---|
| 5V IN | VCC do WS2812B + 5V OUT |
| GND IN | GND do WS2812B + GND OUT |
| DATA IN | DIN do WS2812B |
| DATA OUT | DOUT do WS2812B → próximo módulo |

## Componentes passivos

| Item | Onde | Qty |
|---|---|-----|
| Resistor **470Ω** | **Cada módulo:** DATA IN → DIN do WS2812B | **4** |
| Resistor **470Ω** | **Medusa:** D5 e D6 antes dos XLR TUBO/MOD | **2** |
| Capacitor **470µF–1000µF** | **Cada módulo:** 5V/GND no LED | **4** |
| Capacitor **1000µF** | **Medusa:** barramento 5V na fonte | **1** |
| — | Tubo: cap opcional no conector de entrada | 0–1 |

Sem MOSFET nem driver CC na v0.

## Proteção

| Risco | Mitigação v0 |
|---|---|
| USB só alimentando 4 LEDs | Usar **fonte 5V 1A** para VCC dos LEDs |
| Data longa | Cabos < 30 cm entre módulos no protótipo |
| 5V em LED | WS2812B **não** ligar em 24V |

Anti-reverso P4 é especificação **v1** — na v0, observar polaridade 5V/GND manualmente.

## Pinagem alternativa

Alterar em `promicro-4mod.ino`:

```cpp
#define LED_PIN 6   // trocar para 5, 7, 8… se D6 ocupado
```

## Teste sem MIDI

Boot sequence no `setup()` acende cada LED em sequência (R, G, B, W nos 4 módulos). Se um não acender:

1. Verificar ordem na cadeia DIN→DOUT
2. Trocar `COLOR_ORDER`
3. Medir 5V no LED

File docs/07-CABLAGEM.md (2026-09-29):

# Cablagem — v0

**Conectores XLR (opcional):** pinagem e cadeia módulos + tubo — [16-XLR-CONECTORES.md](16-XLR-CONECTORES.md).

Cada ligação entre módulos usa **3 fios** (ou **XLR 3 pinos** com a mesma função):

| Fio | Função |
|-----|---|
| **Vermelho** | 5V |
| **Preto** | GND |
| **Branco/verde** | DATA (WS2812B) |

## Diagrama completo

```
[Fonte 5V] ──┬── VCC Pro Micro
             ├── VCC ──┬── Mod1 ──┬── Mod2 ──┬── Mod3 ──┬── Mod4
             └── GND ──┴── GND ───┴── GND ───┴── GND ───┴── GND

Pro Micro D6 ──[470Ω]──► DATA IN Mod1 ──► OUT ──► IN Mod2 ──► ... ──► Mod4
Pro Micro D5 ──[470Ω]──► DATA tubo neon (cabo XLR separado dos módulos)
```

## Por módulo (padrão StageMod)

**Cada um dos 4 módulos** leva **470 Ω** na entrada de DATA e **capacitor** na alimentação do LED.

```
     XLR IN (ou chicote IN)
  Pin3 DATA ──[470Ω]──► DIN    DOUT ───► DATA OUT (→ próximo módulo)
  Pin2 5V  ──┬── VCC LED
  Pin1 GND ──┴── GND LED
              │
         [470µF–1000µF]
         entre 5V e GND
              │
  Pin2/1 pass-through ───────► XLR OUT (5V/GND)
```

| Componente | Onde no módulo |
|---|---|
| **470 Ω** | Entre **DATA IN** (pino 3 do XLR) e **DIN** do WS2812B |
| **470 µF–1000 µF** (≥ 6,3 V) | Entre **5 V** e **GND** do LED (o mais perto possível do chip) |

A **Medusa** mantém capacitor no barramento 5 V e **470 Ω** nas saídas **D5** e **D6** antes dos XLR MOD/TUBO — ver [17-CABECA-MEDUSA.md](17-CABECA-MEDUSA.md).

## Ordem da cadeia

| Posição | Índice | Nota MIDI |
|---|---|---|
| Mais perto do Pro Micro | 0 | C3 |
| 2º | 1 | D3 |
| 3º | 2 | E3 |
| Último | 3 | F3 |

**Importante:** DATA sai do **DOUT** de um módulo e entra no **DIN** do próximo.

## Comprimentos sugeridos

| Trecho | Comprimento |
|---|---|
| Pro Micro → Mod 1 | 10–30 cm |
| Mod → Mod | 20–50 cm |
| DATA total | < 1 m ideal |

## Identificação

| Etiqueta | Significado |
|---|---|
| `MOD 1` … `MOD 4` | Ordem na cadeia |
| Seta no DATA | IN → OUT |

## Montagem — ordem

1. Fonte **desligada**
2. Soldar GND comum em todos
3. Soldar 5V em todos
4. Ligar DATA: D6 → Mod1 → Mod2 → Mod3 → Mod4
5. Em **cada** módulo: soldar **470 Ω** (DATA IN → DIN) e **cap** (5V/GND no LED)
6. Ligar fonte; verificar boot RGB

## Splits / topologia

v0 usa **uma linha** apenas:

```
[Pro Micro]──[M1]──[M2]──[M3]──[M4]
```

Splits em T na linha DATA **não** são suportados sem repetidor — planejado para v1.

## v1 cablagem

P4 + RJ45 — [v1/09-CABLAGEM.md](v1/09-CABLAGEM.md).

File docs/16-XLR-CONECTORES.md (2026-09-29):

# Conectores XLR — v0

Conectores **XLR 3 pinos** para ligar o **tubo neon** e os **módulos WS2812B** com cabo de palco (desmontagem rápida, padrão familiar).

## O que vai em cada XLR (3 fios)

| Pino XLR | Sinal | Função |
|---|---|---|
| **1** | **GND** | Terra comum (shell do XLR também ligado ao GND) |
| **2** | **+5V** | Alimentação DC |
| **3** | **DATA** | Linha addressable (DIN / DOUT) |

**Não é áudio:** não ligar em mesa/microfone. Etiquetar cabos: `5V PIXEL — NÃO PHANTOM`.

### Convenção IN / OUT (módulos)

| Conector no módulo | Tipo | Ligação interna |
|---|---|---|
| **Entrada** | XLR **fêmea** (painel) | 5V/GND passam; **DATA → [470Ω] → DIN**; **cap** 5V/GND no LED |
| **Saída** | XLR **macho** (painel) | 5V/GND passam; **DOUT → DATA** do cabo |

Os módulos ligam em **cadeia na DATA** (série lógica), não em paralelo na linha de dados:

```
Cabeça ──DATA──► Mod1 ──DATA──► Mod2 ──DATA──► Mod3 ──DATA──► Mod4
         5V/GND em paralelo em todos os pontos (mesma fonte)
```

**5V e GND** são **paralelos** em todo o rig (fonte, tubo, cada módulo). Só a **DATA** “salta” de módulo em módulo via DOUT→DIN.

## Cabeça (Pro Micro)

Montagem recomendada: caixa **Medusa** com XLR no painel — [17-CABECA-MEDUSA.md](17-CABECA-MEDUSA.md).

Dois ramos de dados no firmware:

| Ramo | Pino MCU | Destino |
|---|---|---|
| Módulos | **D6** | XLR → entrada do **Módulo 1** |
| Tubo | **D5** | XLR → entrada do **tubo** (único conector hoje) |

```
                    ┌── XLR OUT "MÓDULOS" (D6 + 5V + GND) ──► Mod1 IN
[Fonte 5V]──┬──[Pro Micro]
            └── XLR OUT "TUBO"   (D5 + 5V + GND) ──► Tubo IN
```

Resistor **470Ω** entre **D6** e o pino 3 do XLR dos módulos; outro **470Ω** entre **D5** e o pino 3 do XLR do tubo (pode ficar na cabeça ou no primeiro centímetro do cabo).

## Tubo (4 m, um XLR hoje)

| Situação | Ligação |
|---|---|
| **Agora** | Um cabo XLR da cabeça **TUBO** → XLR do tubo (5V, GND, DATA no D5) |
| **Futuro: 4× 1 m** | Cada metro com **IN + OUT** XLR; DATA em cadeia: Cabeça → T1 → T2 → T3 → T4 |

```
Hoje:
  Cabeça (D5) ──XLR──► [ Tubo 4 m ]

Futuro (4 segmentos):
  Cabeça (D5) ──► [T1] ──► [T2] ──► [T3] ──► [T4]
                  IN/OUT   IN/OUT   IN/OUT   IN/OUT
```

- `NUM_TUBE_LEDS` continua **200** (50 LED/m × 4 m) se a cadeia DATA for contínua.
- Com **4 m**, injete **+5V e GND** de novo no **meio** do tubo (e opcionalmente em cada segmento de 1 m), mesmo usando XLR — o pino 2/1 carregam corrente; fio fino no cabo XLR longo pode aquecer.

## Diagrama módulos (XLR)

```
     XLR IN (F)              WS2812B              XLR OUT (M)
  Pin1 GND ──────────────── GND ───────────────── Pin1 GND
  Pin2 5V  ────┬─────────── 5V  ───────────────── Pin2 5V
               │ [470µF–1000µF]
  Pin3 DATA ──[470Ω]──► DIN    DOUT ───► Pin3 DATA
```

Ordem na cadeia: **Mod1** (C3) → **Mod2** (D3) → **Mod3** (E3) → **Mod4** (F3).

## Cabos

| Cabo | Comprimento típico | Observação |
|---|---|---|
| Cabeça → Mod1 | 0,5–2 m | DATA = saída D6 |
| Mod → Mod | 0,3–1 m | Macho do anterior → fêmea do próximo |
| Cabeça → tubo | 1–5 m | DATA = saída D5 |
| Segmento tubo → tubo | 0,2–0,5 m | Só ao dividir em 1 m |

Use condutor **AWG 18–20** no par 5V/GND se o cabo alimentar trecho longo de LED; AWG 22–24 basta para DATA curta.

## O que comprar (AliExpress)

| Item | Busca |
|---|---|
| XLR 3 pinos fêmea painel | `XLR 3 pin female panel mount connector` |
| XLR 3 pinos macho painel | `XLR 3 pin male panel mount connector` |
| Cabo microfone (para montar) | `microphone cable 2 core + shield` — usar condutores para 5V e DATA; malha = GND |

Marcas de palco (Neutrik, etc.) aguentam melhor corrente e encaixe; clones baratos servem para protótipo com corrente moderada.

## Limitações

| Tema | Detalhe |
|---|---|
| Corrente no XLR | Contatos típicos **≤ 5–8 A** por par; tubo 4 m: preferir **fonte na cabeça** + **injeção 5V** no tubo com cabo mais grosso, não só pelo XLR longo |
| Dois DATA | Tubo (D5) e módulos (D6) **não** compartilham o mesmo pino 3 — são **dois cabos XLR** da cabeça (ou um cabo 5 pinos, se padronizar depois) |
| Mistura com áudio | Pinagem parecida com alguns usos, mas tensão é **5 V DC** — risco se plugar em entrada de linha |

## Checklist de montagem

1. Definir pinagem **1=GND, 2=+5V, 3=DATA** em todos os conectores.
2. Shell do XLR ligado ao **GND** em ambos os lados.
3. Testar continuidade antes de ligar a fonte.
4. Primeiro teste: **1 módulo** + cabo XLR; depois cadeia completa + tubo.
5. Etiquetas: `MOD`, `TUBO`, `D5`, `D6`, direção **IN → OUT**.

## Referências

- Cabos gerais: [07-CABLAGEM.md](07-CABLAGEM.md)
- Tubo D15 / 200 LEDs: [14-TUBO-FLEX.md](14-TUBO-FLEX.md)
- Firmware D5/D6: [firmware/promicro-4mod/](../firmware/promicro-4mod/)

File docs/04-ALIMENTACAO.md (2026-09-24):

# Alimentação — v0 (5V)

## Fonte

| Item | Especificação |
|---|---|
| Tensão | **5 V DC** |
| Corrente mínima | **1 A** (recomendado **2 A**) |
| Tipo | USB charger, buck 5V, fonte bench |

## Dimensionamento

| Carga | Corrente |
|---|---|
| 4× WS2812B branco 100% | ~**240 mA** |
| Pro Micro | ~**50 mA** |
| 4 módulos apenas | ~300 mA |
| + tubo 30 LED | ~**2 A** |
| + tubo 60 LED | ~**3,5 A** |
| + tubo 4 m (200 LED) | ~**12 A** pico branco total / **~2,5 A** nominal (manual: 3,1 W/m) |

| Config | Fonte 5V |
|---|---|
| Só 4 módulos | **1 A** |
| Módulos + tubo curto (≤1 m) | **3 A** |
| Módulos + tubo **4 m** (D15) | **5 A** mínimo / **10 A** se branco alto + injeção 5V a cada ~2 m |

## Medusa — entrada C14

Na cabeça, a rede entra por **conector C14** (cabo **C13**); a fonte **5 V 10 A** fica **dentro** da caixa. Esquema e segurança: [17-CABECA-MEDUSA.md](17-CABECA-MEDUSA.md#entrada-de-rede--conector-c14).

## Como ligar (5 V DC)

```
[SMPS 5V na Medusa] ──┬── (+) Pro Micro VCC
                      ├── (+) Módulo1…4 VCC (em paralelo ou cadeia)
                      └── (−) GND comum a todos
```

### USB do PC

- OK para **programar** e testar **1 LED**
- **Não** recomendado para 4 LEDs full white contínuo (limite ~500 mA do USB com risco de queda)

## Limitação de módulos @ 5V

| Fator | Limite v0 |
|---|---|
| Firmware | **4 módulos** (`NUM_MODULES`) |
| Corrente | Escala linear — 8 LEDs ≈ 500 mA → fonte 1A ainda OK |
| Queda de tensão | AWG fino longo → cores instáveis no fim da cadeia |

Para **mais brilho** ou **muitos módulos**, planejar **v1** com 24V — [v1/README.md](v1/README.md).

## Tabela rápida

| LEDs WS2812 @ 5V | Corrente max ~ | Fonte sugerida |
|---|---|---|
| 4 | 0,25 A | 1 A |
| 8 | 0,5 A | 1 A |
| 16 | 1 A | 2 A |
| 32 | 2 A | 3 A |

## Erros a evitar

| Erro | Consequência |
|---|---|
| Ligar 24V nos WS2812B | Destrói LEDs |
| GND desconectado | Comportamento errático / sem comunicação |
| Sem capacitor no 1º LED | Piscadas aleatórias |

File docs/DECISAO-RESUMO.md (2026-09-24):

# Resumo — StageMod v0

## Em uma frase

**Medusa** (Pro Micro + **ZS-040**) + **4 módulos WS2812B RGB**. MIDI: **Bluetooth** no palco ou **USB** quando a cabeça está perto.

```
DAW ──BT──► [ZS-040]──► [Pro Micro] ──D6──► [Mod1]──► … ──►[Mod4]
     └──USB (opc.)──────►      └── C14 + SMPS 5V 10A na Medusa
```

## Decisões v0

| Tópico | Escolha |
|---|---|
| Cabeça | **Pro Micro + ZS-040** na [Medusa](17-CABECA-MEDUSA.md) |
| Módulos | **4×**, 1 WS2812B cada |
| Cor | **RGB completo** (CC 1–14) |
| Alimentação | **5V** / 1A |
| Dados | **1 fio** WS2812 (pin D6) |
| Spot | D6 — 5V + GND + DATA (fios ou XLR IN/OUT em cadeia) |
| Tubo flex | D5 — tubo neon WS2811, XLR único (4×1 m no futuro) |
| Conectores | [XLR 3 pin](16-XLR-CONECTORES.md): 1=GND, 2=+5V, 3=DATA |
| Cabeça física | Medusa — Pro Micro + ZS-040 + XLR; **USB** quando perto do PC |

## MIDI rápido

| Módulo | R | G | B | Nota |
|---|---|---|---|---|
| 1 | CC1 | CC2 | CC3 | C3 |
| 2 | CC4 | CC5 | CC6 | D3 |
| 3 | CC9 | CC10 | CC11 | E3 |
| 4 | CC12 | CC13 | CC14 | F3 |

- **CC7** = dimmer · **PC0** = blackout · **PC1–6** = presets cor

## Firmware

`firmware/promicro-4mod/promicro-4mod.ino`

## Ligação mínima

- D6 → 470Ω → DIN módulo 1
- 5V/GND em paralelo nos 4 LEDs
- Cap 470µF no 1º módulo

## Limites

- **4 módulos** (firmware)
- **~250 mA** max @ 5V
- Palco pequeno / efeito — não wash 10W

## v1 (depois)

ESP32, 24V, 2×10W, P4+RJ45 — [v1/README.md](v1/README.md)

## Próximo passo

Montar hardware → upload → [08-ROADMAP.md](08-ROADMAP.md)

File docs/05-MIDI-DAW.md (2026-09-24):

# MIDI e DAW — v0

Firmware: `firmware/promicro-4mod/promicro-4mod.ino`

## Fluxo

```
DAW ──USB MIDI──► Pro Micro ──► FastLED ──► 4× WS2812B RGB
```

**Palco:** DAW → Bluetooth → **ZS-040** → Serial1. **Perto do PC:** MIDI **USB** no Pro Micro. [18-WIRELESS-MIDI.md](18-WIRELESS-MIDI.md).

## Mapa MIDI — RGB por módulo

Cada módulo: **3 Control Changes** (R, G, B). Valor DAW 0–127 → LED 0–255.

| Módulo | Vermelho | Verde | Azul |
|---|---|---|---|
| **1** | CC **1** | CC **2** | CC **3** |
| **2** | CC **4** | CC **5** | CC **6** |
| **3** | CC **9** | CC **10** | CC **11** |
| **4** | CC **12** | CC **13** | CC **14** |

| CC | Função |
|----|---|
| **7** | Master dimmer (módulos + tubo) |

## Tubo flexível — CC 15–19

| CC | Função |
|----|---|
| **15** | Efeito: 0=off · chase · **gradient wave** · rainbow · solid |
| **16** | Matiz (cor base) |
| **17** | Velocidade da animação |
| **18** | Densidade / largura das manchas de luz |
| **19** | Brilho (modo sólido) |

| PC | Preset tubo |
|----|---|
| **7** | Gradient wave (efeito `--- -- -` em movimento) |
| **8** | Chase / cometa |
| **9** | Rainbow |
| **10** | Tubo off |

Detalhes: [14-TUBO-FLEX.md](14-TUBO-FLEX.md).

## Notas (gatilho + brilho)

| Nota | Módulo | Comportamento |
|---|---|---|
| **60** (C3) | 1 | Acende com RGB dos CC 1–3; **velocity** = brilho |
| **61** (D3) | 2 | CC 4–6 |
| **62** (E3) | 3 | CC 9–11 |
| **63** (F3) | 4 | CC 12–14 |
| Note off | — | Apaga o módulo |

## Program Change (presets)

| PC | Preset | Cor (todos os módulos) |
|----|---|---|
| **0** | Blackout | Apagado |
| **1** | Warm white | RGB(255, 180, 80) |
| **2** | Vermelho | RGB(255, 0, 0) |
| **3** | Verde | RGB(0, 255, 0) |
| **4** | Azul | RGB(0, 0, 255) |
| **5** | Magenta | RGB(255, 0, 255) |
| **6** | Branco | RGB(255, 255, 255) |

## Canal MIDI

```cpp
#define MIDI_CHANNEL 1   // alterar; 0 = omni
```

## Configuração no DAW

### Reaper

1. Preferences → MIDI → habilitar dispositivo USB do Pro Micro
2. Track com saída MIDI → Pro Micro
3. Envelope ou knobs nos CC 1–14

### Ableton Live

1. Preferences → Link/MIDI → Track On no Pro Micro
2. MIDI mapping nos knobs para CC 1–14

## Exemplo de uso

1. `CC1=127, CC2=0, CC3=0` → módulo 1 vermelho
2. `CC2=127` → amarelo
3. `CC1=127, CC3=127` → magenta
4. Nota C3 velocity 100 → módulo 1 com ~80% do brilho

## Latência

| Trecho | Tempo típico |
|---|---|
| USB MIDI | 1–3 ms |
| FastLED update | < 1 ms |

## v1 (futuro)

MIDI na Cabeça ESP32 + RS-485 para módulos 10W — mapa em evolução; ver [v1/README.md](v1/README.md).

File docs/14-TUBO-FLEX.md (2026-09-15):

# Tubo flexível LED — gradiente e chase (v0)

Além dos **4 módulos spot** (1 WS2812B cada), o protótipo v0 suporta um **tubo flexível** com dezenas de LEDs endereçáveis — ideal para efeitos de **gradiente**, **ondas** e **chase** ao longo do comprimento.

## Visual do efeito

O efeito **Gradient Wave** move manchas de luz de larguras diferentes pelo tubo:

```
tempo →
██████          ██    ███   █         █████
  (longo)      (curto)(médio)(ponto)   (longo)
```

Equivalente ao padrão que você descreveu: traços acesos de tamanhos variados deslizando pelo tubo.

## Hardware

| Item | Especificação |
|---|---|
| LED | **D15-Woven Magic** — tubo silicone Ø15 mm, **WS2811**, **50 LED/m** |
| Tensão | **5 V** (mesma fonte dos módulos) |
| Data | **Pin 5** do Pro Micro (separado dos módulos no pin 6) |
| Quantidade | `NUM_TUBE_LEDS` no firmware — **200** para tubo 4 m @ 50 LED/m |

### Onde comprar

Tubo neon pronto — a fita addressable **já vem dentro** do silicone. Busca: `WS2812B neon flex` / `LED neon tube addressable 5V`.

### Ligação

```
[Fonte 5V] ──┬── módulos (pin 6) + tubo (pin 5)
             └── GND comum

Pro Micro D6 ──► módulos 1–4 (cadeia)
Pro Micro D5 ──► DIN da fita no tubo
```

| Pino Pro Micro | Destino |
|---|---|
| **D6** | 4× módulos spot |
| **D5** | Tubo flexível neon (WS2811/WS2812B integrado) |

Resistor **470Ω** em cada linha de data (D5 e D6). Capacitor **1000µF** no início de cada alimentação 5V.

### Corrente

| LEDs no tubo | Corrente max ~ |
|---|---|
| 30 | ~1,8 A |
| 60 | ~3,6 A |
| 200 (4 m) | ~**12 A** pico / **4–6 A** em efeitos |

Com 4 módulos + tubo **4 m**: fonte **5V / 10A** + injeção de 5V a cada ~1–2 m.

## Efeitos no firmware

| ID | Nome | Descrição |
|----|---|---|
| 0 | Off | Tubo apagado |
| 1 | **Chase** | Cometa com rastro que corre o tubo |
| 2 | **Gradient Wave** | Ondas de luz de larguras variadas (padrão `--- -- -`) |
| 3 | Rainbow | Arco-íris estático ao longo do tubo |
| 4 | Solid | Cor única em todo o tubo |

## MIDI — controle do tubo

| CC | Função | Valores |
|----|---|---|
| **15** | Efeito | 0=off · baixo=chase · médio=wave · alto=rainbow/solid |
| **16** | Matiz (hue) | Cor base do efeito |
| **17** | Velocidade | Animação chase / wave |
| **18** | Densidade | Largura das manchas / tamanho do rastro |
| **19** | Brilho | Modo sólido |

| PC | Preset |
|----|---|
| **7** | Gradient wave (azul, velocidade média) |
| **8** | Chase vermelho |
| **9** | Rainbow |
| **10** | Tubo off |
| **0** | Blackout (módulos + tubo) |

**CC 7** (master dimmer) afeta módulos e tubo.

## Configurar quantidade de LEDs

Em `promicro-4mod.ino`:

```cpp
#define NUM_TUBE_LEDS 200   // tubo 4 m @ 50 LED/m (padrão BTF reticulate)
```

| Comprimento | 50 LED/m | 60 LED/m | 30 LED/m |
|---|---|---|---|
| 0,5 m | 25 | 30 | 15 |
| 1 m | 50 | 60 | 30 |
| 2 m | 100 | 120 | 60 |
| **4 m** | **200** | **240** | 120 |

### Tubo comprado (4 m) — manual D15-Woven Magic

| Campo | Valor |
|---|---|
| Modelo | **D15-Woven Magic** |
| Anúncio | [AliExpress 1005006239466933](https://pt.aliexpress.com/item/1005006239466933.html) |
| Comprimento | **4 m** |
| Tensão | **5 V DC** |
| Chip | **WS2811** (IC 2811) — não é WS2812B |
| LEDs/m | **50** (corte a cada **20 mm**) |
| Potência | **3,1 W/m** → ~12,4 W total (~2,5 A nominal) |
| IP | **IP67** |
| `NUM_TUBE_LEDS` | **200** |

### Fios do conector (3 pinos)

| Fio | Função |
|-----|---|
| **Vermelho** | +5V |
| **Do meio** | **DATA** (DIN) → Pro Micro **D5** |
| **Externo** | GND |

Resistor **470Ω** entre D5 e DATA. **Não use o controle RF** do kit.

### Firmware

Módulos = `WS2812B` (pin 6). Tubo = `WS2811` (pin 5). Se as cores do tubo saírem trocadas, altere `TUBE_COLOR_ORDER` para `GRB` no `.ino`.

## Boot

Após os 4 módulos piscarem R/G/B/W, o tubo executa um **gradient wave** de teste. Se o tubo não estiver ligado, comentar `bootTestTube();` no `setup()`.

## Sem tubo ainda?

- Deixar `NUM_TUBE_LEDS` como está ou definir **0** (requer remover `addLeds` do tubo no código)
- Ou simplesmente não ligar o fio no D5 — módulos spot funcionam normalmente

## v1

Tubo pode evoluir para perfil de palco maior ou segundo barramento RS-485 — por ora é saída direta do Pro Micro.

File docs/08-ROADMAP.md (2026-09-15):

# Roadmap

## v0 — atual ✅ / em montagem

| # | Tarefa | Status |
|---|---|---|
| 0.1 | Documentação v0 | ✅ |
| 0.2 | Firmware `promicro-4mod` + RGB CC 1–14 | ✅ |
| 0.2b | Tubo flex D5 + gradient wave / chase | ✅ |
| 0.3 | Montar 4 módulos WS2812B + fonte 5V | 🔲 |
| 0.4 | Upload + boot test (R,G,B,W) | 🔲 |
| 0.5 | MIDI no DAW — CC cores + notas C3–F3 | 🔲 |
| 0.6 | Presets PC 0–6 testados | 🔲 |
| 0.7 | Carcaça mecânica básica (opcional) | 🔲 |

## v0.1 — melhorias opcionais

| # | Tarefa |
|---|---|
| 0.8 | Fade suave entre cores (no firmware) |
| 0.9 | Aumentar para 6–8 módulos (`NUM_MODULES`) |
| 0.10 | Salvar presets em EEPROM |

## v1 — rig de palco (planejado)

Migrar conceito MIDI validado na v0 para hardware de palco:

| # | Marco |
|---|---|
| 1.1 | Cabeça **ESP32-S3** + MIDI USB |
| 1.2 | Barramento **P4 (24V) + RJ45 (RS-485)** |
| 1.3 | Módulo **Dual 2× 10W** (WW + vermelho) + ATtiny |
| 1.4 | Lente **20mm 90°** |
| 1.5 | Anti-reverso **IRF9540N** na Cabeça |
| 1.6 | `modules.json` — perfis por módulo |

Especificação completa: [v1/README.md](v1/README.md).

## Estrutura do repositório

```
/
├── README.md                 # v0
├── docs/
│   ├── 00–08, DECISAO        # documentação v0
│   └── v1/                   # especificação futura
├── firmware/
│   └── promicro-4mod/        # firmware v0
└── (v1: head/, module/, kicad/ — ainda não criados)
```

## Critério para iniciar v1

- [ ] v0 controla 4 módulos de forma estável no DAW por 1+ ensaio
- [ ] Mapa MIDI (CC + notas) validado
- [ ] Decisão: quantos módulos 10W no rig final (4, 8, 12)

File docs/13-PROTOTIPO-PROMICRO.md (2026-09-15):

# Protótipo Pro Micro — redirecionamento

A documentação do protótipo foi **unificada na v0**.

| Antes | Agora |
|---|---|
| Este arquivo como “protótipo” separado | Toda a doc principal é **v0** |

## Onde está cada tema

| Tema | Documento |
|---|---|
| Visão geral | [00-VISAO-GERAL.md](00-VISAO-GERAL.md) |
| Arquitetura | [01-ARQUITETURA-MODULAR.md](01-ARQUITETURA-MODULAR.md) |
| LEDs WS2812B | [02-LEDS-E-OPTICA.md](02-LEDS-E-OPTICA.md) |
| Eletrônica | [03-ELETRONICA.md](03-ELETRONICA.md) |
| Alimentação 5V | [04-ALIMENTACAO.md](04-ALIMENTACAO.md) |
| MIDI | [05-MIDI-DAW.md](05-MIDI-DAW.md) |
| BOM | [06-BOM.md](06-BOM.md) |
| Cablagem | [07-CABLAGEM.md](07-CABLAGEM.md) |
| Firmware | [firmware/promicro-4mod/](../firmware/promicro-4mod/) |

## v1 (rig 24V futuro)

[v1/README.md](v1/README.md)

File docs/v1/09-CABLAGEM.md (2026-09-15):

# Cablagem v1 — energia P4 + cabo de dados separado

> **Planejado v1** — não implementado. Projeto atual: [v0](../07-CABLAGEM.md).

Para **baratear**, o StageMod **não** usa cabo especial 5 vias. São **dois chicotes independentes** em cada ligação:

| Chicote | Função | Conector | Cabo comum |
|---|---|---|---|
| **Energia** | 24 V + GND | **P4** (DC barrel) | Fio 2× AWG18 + plug P4 macho/fêmea |
| **Dados** | RS-485 A / B | **RJ45** | Patch **Cat5e** (um par trançado) |

O **GND de dados** é o mesmo GND da alimentação — ligado na PCB do módulo (não precisa de fio extra no cabo de rede se o par RS-485 referencia o GND da fonte via módulo).

## Por que separar

| Cabo único GX16-5 | P4 + RJ45 |
|---|---|
| Conector aviação ~US$ 2/par | P4 ~US$ 0,15 + RJ45 ~US$ 0,20 |
| Cabo 5 condutores especial | Sobra de **Cat5e** + fio silicone 2× |
| Um erro mistura V+ com dados | Energia e dados fisicamente separados |
| Difícil de repor em campo | **P4 e RJ45 em qualquer loja** |

## Energia — plug P4

### Padrão adotado

| Item | Especificação |
|---|---|
| Conector | **DC barrel 5,5 mm × 2,1 mm** (P4 comum) |
| Polaridade | **Centro = V+** · Externo = GND |
| Proteção anti-reverso | **Só na Cabeça (P4 OUT)** — única fonte do rig — ver [03-ELETRONICA.md](03-ELETRONICA.md) |
| Tensão | 24 V DC |
| Corrente por ligação P4 | ≤ **2 A** contínuo (patch entre 2 módulos) |

> P4 de CCTV/fonte notebook aguenta bem ~1,2 A por módulo. **Não** passar 10 A do rig inteiro por uma cadeia longa só de P4 — usar **distro** com fio grosso e várias derivações P4.

### Por módulo (pass-through)

```
[P4 IN centro] ── V+ ── polyfuse 2A ──┬── drivers
[P4 IN casco]  ── GND ───────────────┤
[P4 OUT]       ── (pass-through) ────┘
```

Anti-reverso **não** vai no módulo — apenas **polyfuse 2 A** no IN.

Entre módulos: cabo **P4 macho → macho** (extensão DC barata) ou **macho → fêmea** conforme o que estiver no módulo.

```
Cabeça/Fonte ──P4──► Mód1 IN ── (bus interno) ── Mód1 OUT ──P4──► Mód2 IN ── ...
```

### Cabo de energia DIY

| Trecho | Condutor | Conector |
|---|---|---|
| Patch módulo→módulo | 2× **AWG18** silicone 30–50 cm | P4 macho nos dois lados |
| Fonte → distro | AWG16 | P4 ou borne |
| Distro → primeiro módulo | AWG18 | P4 |

**Custo patch energia:** ~US$ 0,50–1,00 (fio + 2 plugs P4).

## Dados — cabo de rede simples

### Padrão adotado

| Item | Especificação |
|---|---|
| Cabo | **Cat5e** (patch ou sobra) |
| Conector | **RJ45** 8P8C |
| Protocolo | RS-485 half-duplex |
| Par usado | **Pin 4 + 5** (par azul) = D+ / D− *ou* pin 1 + 2 (par laranja) — **fixar no projeto e não mudar** |

### Pinagem RJ45 StageMod (T568B — par azul = RS-485)

| Pin | Cor T568B | Sinal |
|-----|---|---|
| 4 | Azul | **D+** (RS-485 A) |
| 5 | Azul/branco | **D−** (RS-485 B) |
| Outros | — | NC (reserva futura) |

GND da RS-485 = **GND do P4** no módulo (ligação na PCB, não no RJ45).

### Pass-through no módulo

```
[RJ45 IN]  pin4 ──────────────── pin4  [RJ45 OUT]
           pin5 ──────────────── pin5
           (ligação direta, sem MAX485 no caminho dos fios)
           
MAX485 do módulo: A/B ligados ao par 4-5 do IN (stub curto na PCB)
```

Cabo entre módulos: **patch Cat5e** qualquer (0,3–1 m).

**Custo patch dados:** ~US$ 0,30–0,80 (cabo + 2 RJ45 se crimpado em casa).

## Ligação completa entre dois módulos

```
Módulo 1                          Módulo 2
┌─────────────────┐              ┌─────────────────┐
│ P4 IN    P4 OUT │── cabo P4 ──►│ P4 IN    P4 OUT │
│ RJ45 IN RJ45 OUT│── Cat5e ────►│ RJ45 IN RJ45 OUT│
└─────────────────┘              └─────────────────┘
```

Dois cabos por salto — ainda **muito mais barato** que GX16-5 + cabo 5 vias.

## Cabeça (Head Unit) — única fonte + proteção

| Conector | Função |
|---|---|
| **P4 IN** | Fonte 24 V (centro +) |
| **P4 OUT** | **Saída protegida** → toda a cadeia de módulos |
| **RJ45** | RS-485 → M1 |
| **USB** | MIDI / DAW |

```
Fonte ──► P4 IN [Cabeça: P-MOS anti-reverso] ──► P4 OUT ──► M1 ──► M2 ──► ...
```

| Item na Cabeça | Especificação |
|---|---|
| Anti-reverso | **P-MOS IRF9540N** (TO-220) no tronco de saída |
| Após proteção | Polyfuse **10 A** + TVS SMBJ24A |
| Buck ESP | Alimentado do barramento **já protegido** |

Detalhe do circuito: [03-ELETRONICA.md](03-ELETRONICA.md).

**Teste:** inverter cabo na fonte ou no P4 OUT → corrente ≈ 0 em todo o rig.

## Split em T

Dois adaptadores baratos:

| Adaptador | Tipo | Função |
|---|---|---|
| **T-P4** | 1 P4 fêmea → 2 P4 fêmea | Ramo de energia |
| **T-RJ45** | 1 RJ45 → 2 RJ45 (pin 4-5 em paralelo) | Ramo de dados |

DIY: soquete RJ45 triplo ou cabo Y Cat5e. Para palco ≤ 12 módulos costuma bastar.

## Terminação RS-485

Resistor **120 Ω** entre D+ e D− no **último** módulo de cada ramo longo (jumper na PCB, no par 4-5).

## Identificação

| Etiqueta | Significado |
|---|---|
| Fita **vermelha** no P4 | Lado que vem da fonte / V+ |
| Cabo **azul** ou curto | Dados (RJ45) |
| Cabo **preto** grosso | Energia (P4) |

## Limites e cuidados

| Risco | Mitigação |
|---|---|
| P4 invertido na fonte/OUT | **Anti-reverso na Cabeça** bloqueia; etiqueta vermelha no centro + |
| P4 invertido entre módulos | Evitar com cabos certificados; módulos não têm anti-reverso |
| Corrente alta num P4 só | Máx. ~2 A por patch; distro com AWG16 |
| Ruído RS-485 | Par trançado Cat5e; não enrolar dados junto do P4 por metros |
| GND flutuante | GND P4 = GND MAX485 em cada módulo |

## Checklist montagem

- [ ] P4: centro = +24 V em todos os cabos
- [ ] Cabeça: cabo invertido na fonte/OUT → corrente **≈ 0 A** em todo o rig
- [ ] RJ45: pin 4-5 contínuo IN→OUT em cada módulo
- [ ] Sem curto V+ ↔ GND na entrada P4
- [ ] Terminação 120 Ω só no fim do ramo dados
- [ ] Cabo Cat5e não precisa ser blindado para < 15 m

## Comparativo de custo (1 salto módulo→módulo)

| Item | GX16-5 (antigo) | P4 + RJ45 |
|---|---|---|
| Conectores | ~US$ 4 | ~US$ 0,35 |
| Cabo | ~US$ 3 | ~US$ 0,40 |
| **Total / salto** | **~US$ 7** | **~US$ 0,75** |

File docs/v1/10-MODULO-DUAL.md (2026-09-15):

# Módulo Dual v1 — 2× 10 W, sem ESP

> **Planejado v1** — não implementado. Projeto atual: [v0](../00-VISAO-GERAL.md).

Módulo luminoso **simples**: apenas drivers, decodificador de barramento e dois soquetes de LED. Toda inteligência fica na **Cabeça** (único ESP32).

## Especificação v1 (padrão de fábrica)

| Canal | LED padrão | Potência | Corrente típica |
|---|---|---|---|
| **A** | Warm white 3000 K | 10 W | ~900–1050 mA |
| **B** | Vermelho 620–630 nm | 10 W | ~900–1050 mA |

Potência máxima do módulo: **~20 W** (+ perdas driver ≈ 22–25 W do barramento 24 V → **~1,0–1,2 A** por módulo).

## Bloco funcional

```
IN (P4 + RJ45) ──► pass-through OUT
         │
    ┌────┴────────────────────────────┐
    │  MAX485  ◄──► ATtiny (decoder)  │
    │     │              │            │
    │     │         PWM A, PWM B      │
    │     │              │            │
    │  Driver CC A   Driver CC B      │
    │     │              │            │
    │  LED socket A  LED socket B      │
    └─────────────────────────────────┘
```

### Por que um ATtiny no módulo (e não ESP)

| | ESP32 por módulo | ATtiny + MAX485 |
|---|---|---|
| Custo | ~US$ 2,50+ | ~US$ 1,20 |
| Complexidade | Wi‑Fi, flash, antena | só PWM + UART |
| Função | excesso | suficiente |

Não é “cabeça duplicada” — é um **decoder de 2 canais** comparável a um receptor DMX de 2 slots.

## PCB universal — dois soquetes de LED

Mesma placa para todas as combinações futuras:

```
┌─────────────────────────────────────┐
│  [IN]              [OUT]            │
│                                     │
│  (A) ○ lens 20mm    (B) ○ lens 20mm │
│      star 10W           star 10W    │
│                                     │
│  DIP [ADDR 1-8]                     │
└─────────────────────────────────────┘
```

- Soquetes: padrão **star PCB 20 mm** (furo M3) ou solda direta.
- **1 lente PMMA Ø 20 mm, 90°** por canal + holder no heatsink.
- Centros das ópticas: **~30 mm** um do outro.
- Trocar cor = trocar LED + atualizar config na Cabeça (lente reutiliza).
- Detalhes ópticos: [12-LENTE-20MM.md](12-LENTE-20MM.md).

## Entrada P4 — pass-through

O módulo **não** tem anti-reverso — a proteção está na **Cabeça** (única fonte). No IN: **polyfuse 2 A** + TVS, depois pass-through para OUT.

## Drivers 10 W

| Canal | Vf @ 1 A | Driver sugerido |
|---|---|---|
| Vermelho | 2,2–2,8 V | Buck CC **1 A** (XL6001 / PT4115 ajustado) |
| Warm white | 3,0–3,6 V | Idem |

Cada driver:

- Entrada: 24 V do barramento.
- Saída: corrente constante **900 mA** (ajuste uma vez).
- Dim: pino **EN/DIM** ligado ao PWM do ATtiny (ou MOSFET no enable).

**MOSFET IRLB8721** no canal de enable se o módulo buck não aceitar PWM direto no EN.

## Dissipação térmica

20 W contínuos exigem:

- Perfil alumínio **≥ 80 mm** ou carcaça em alumínio usinado.
- Pasta térmica em cada star.
- Lente com **folga de ar** — não transferir calor para PMMA.
- Face frontal da carcaça: orifícios Ø20 mm ou moldura aberta por lente.
- Em gabinete fechado: furos laterais no holder ou ventilação forçada opcional.

Teste de aceite: 30 min a 100 % em ambiente 25 °C → carcaça < 65 °C ao toque.

## Endereço físico

| Método | Bits | Módulos |
|---|---|---|
| DIP-3 | 3 | 1–7 (0 = não usar) |
| DIP-4 | 4 | 1–15 |

Endereço **não** define as cores — só a posição na cadeia lógica. Cores vêm da **config na Cabeça**.

## Configuração lógica (futuro)

Na Cabeça, arquivo `modules.json` (ou portal web):

```json
{
  "modules": [
    { "addr": 1, "ch_a": "warm_white", "ch_b": "red" },
    { "addr": 2, "ch_a": "warm_white", "ch_b": "warm_white" },
    { "addr": 3, "ch_a": "red", "ch_b": "amber" },
    { "addr": 4, "ch_a": "green", "ch_b": "red" }
  ]
}
```

### Tipos de canal suportados (planejado)

| ID | Cor | LED físico |
|----|-----|---|
| `warm_white` | Branco quente 3000 K | Star 10 W WW |
| `cool_white` | Branco frio 6000 K | Star 10 W CW |
| `red` | Vermelho | Star 10 W R |
| `amber` | Âmbar | Star 10 W amber |
| `green` | Verde | Star 10 W G |
| `blue` | Azul | Star 10 W B |
| `off` | Desligado | — |

### MIDI → módulo

A Cabeça traduz:

- **Nota/CC “cor”** → intensidade por **tipo semântico** (ex. “red” acende todos os canais configurados como `red`).
- **CC por módulo** → `addr` + `ch_a` / `ch_b` direto (modo técnico).

Exemplo: Mod 3 = red + amber. Nota “Red” no DAW → só canal A; “Amber” → só canal B.

## Protocolo no barramento (2 canais)

Frame reduzido (Cabeça → módulo `addr`):

```
[SYNC][ADDR][CMD][CH_A][CH_B][CRC]
 0xAA   1-127  0x01  0-255 0-255  xor
```

| CMD | Função |
|-----|---|
| 0x01 | SET_LEVELS imediato |
| 0x02 | FADE ( + 2 bytes tempo ms ) |
| 0x03 | BLACKOUT broadcast |
| 0x10 | PING |

Módulo só responde se `ADDR` = seu DIP ou broadcast `0xFF`.

## BOM por módulo Dual (estimativa)

| Item | Qtd | ~US$ |
|---|-----|---|
| ATtiny1614 ou ATtiny85 | 1 | 0,60 |
| MAX485 | 1 | 0,50 |
| Buck CC 1 A | 2 | 2,00 |
| IRLB8721 (se necessário) | 2 | 1,00 |
| LED 10 W WW + 10 W R | 1+1 | 2,00 |
| P4 fêmea IN + OUT (×2) | 4 | 0,60 |
| RJ45 fêmea IN + OUT (×2) | 4 | 0,80 |
| Heatsink / carcaça Al | 1 | 3,00 |
| Lente PMMA 20 mm 90° | 2 | 0,60 |
| Holder lente 20 mm | 2 | 0,40 |
| PCB | 1 | 2,00 |
| **Total** | | **~16** |

Sem ESP, sem USB, sem Wi‑Fi — módulo **~40 % mais barato** que a versão anterior com ESP32-C3.

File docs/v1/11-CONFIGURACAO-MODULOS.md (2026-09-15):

# Configuração de módulos v1 — combinações de cores

> **Planejado v1** — não implementado. v0 usa CC RGB direto: [05-MIDI-DAW.md](../05-MIDI-DAW.md).

O hardware é **sempre o mesmo**: 2 canais × 10 W. O que muda entre módulos é **qual LED está soldado em cada soquete** e **como a Cabeça mapeia MIDI** para esse módulo.

## Modelo mental

```
         ┌────────────── Cabeça ESP32 ──────────────┐
         │  MIDI → lógica → RS-485                  │
         │  modules.json: addr → (tipo A, tipo B)   │
         └──────────────────┬───────────────────────┘
                            │ P4 + RJ45
         ┌──────────────────┼──────────────────────┐
         ▼                  ▼                      ▼
    Mod 1 (WW+R)      Mod 2 (WW+WW)         Mod 3 (R+Amb)
    DIP addr=1        DIP addr=2            DIP addr=3
```

- **Endereço físico** = DIP no módulo (posição na rede).
- **Perfil lógico** = tipos dos canais A e B (config na Cabeça).
- **LED físico** = deve corresponder ao tipo configurado.

## Exemplos de rig

| Módulo | Addr | Ch A | Ch B | Uso típico |
|---|---|---|---|---|
| 1 | 1 | warm_white | red | Wash quente + acento vermelho |
| 2 | 2 | warm_white | warm_white | Wash branco forte |
| 3 | 3 | red | amber | Sunset / fogo |
| 4 | 4 | green | red | Contraste cênico |
| 5 | 5 | red | red | Backlight vermelho duplo |
| 6 | 6 | warm_white | amber | Pele / warmth |

## Como reconfigurar um módulo

### Só software (mesmos LEDs)

Alterar `modules.json` na Cabeça — útil para renomear papéis MIDI sem abrir o módulo.

### Trocar cor física

1. Desligar fonte 24 V.
2. Substituir star LED no soquete A ou B.
3. Atualizar `ch_a` / `ch_b` na config.
4. Religar; Cabeça envia PING para validar presença do addr.

### EEPROM no módulo (fase futura)

Opcional: byte em ATtiny EEPROM `TYPE_A`, `TYPE_B` para o módulo reportar à Cabeça na boot:

```
PONG: [addr][type_a][type_b]
```

Cabeça sincroniza automaticamente — útil com muitos módulos.

## Paleta MIDI sugerida

### Modo Performance (por cor semântica)

| Nota MIDI | Ação |
|---|---|
| C3 | Todos os canais `red` → velocity |
| D3 | Todos os canais `warm_white` |
| E3 | Todos os canais `amber` |
| F3 | Todos os canais `green` |
| G3 | Blackout global |

### Modo Técnico (por módulo)

| CC | Função |
|----|---|
| CC 20 | Selecionar addr 1–16 |
| CC 21 | Nível ch A |
| CC 22 | Nível ch B |

## Presets (Program Change)

| PC | Nome | Descrição |
|----|---|---|
| 0 | Blackout | Tudo zero |
| 1 | Warm wash | WW em todos os canais WW |
| 2 | Red mood | Red 80 %, WW 20 % nos módulos WW+R |
| 3 | Full warm | Todos WW 100 % |
| 4 | Fire | Amber+red nos módulos configurados |

Presets armazenados em flash da Cabeça.

## Regras de consistência

| Situação | Comportamento |
|---|---|
| Config diz `green`, LED físico é red | Luz acende, cor errada — responsabilidade do instalador |
| Addr DIP duplicado | Dois módulos respondem ao mesmo frame — **evitar** |
| Módulo offline | Cabeça marca slot ausente após 3× PING falho |
| Canal `off` | Driver desligado, PWM 0 |

## Catálogo de LEDs 10 W (referência de compra)

| Tipo | Busca AliExpress/LCSC | Vf @ 1 A |
|---|---|---|
| warm_white | `10W warm white LED star 3000K` | 9–12 V* |
| red | `10W red LED star 620nm` | 6–9 V* |
| amber | `10W amber LED star 590nm` | 9–12 V* |
| green | `10W green LED star` | 9–12 V* |

\* Muitos stars 10 W são **3 chips em série** — usar driver **CC 900 mA**, não tensão fixa.

## Matriz de combinações válidas

Qualquer par `(tipo_A, tipo_B)` onde cada tipo ∈ catálogo acima. Total teórico: N² combinações; na prática 6–8 tipos cobrem palco pequeno.

**Padrão de estoque:** comprar módulos todos **WW + R**; comprar stars avulsas para conversão field.

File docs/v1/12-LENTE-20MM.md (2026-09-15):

# Lente óptica 20 mm v1 — um por LED

> **Planejado v1** — não implementado. v0 usa WS2812B sem lente dedicada.

Cada canal do módulo Dual usa **1 lente de 20 mm** sobre o star 10 W, para concentrar o fluxo útil na área iluminada e reduzir desperdício lateral.

## Por que lente em cada LED

| Sem lente (star nu) | Com lente 20 mm |
|---|---|
| Emissão ~120° Lambertiana — muita luz nas laterais e no gabinete | Feixe controlado **90°** |
| Mancha irregular a 1–2 m | Mancha mais uniforme no palco |
| Parede/gabinete aquece sem contribuir para o wash | Mais lm “úteis” na zona alvo |
| Dois pontos de cor muito separados visualmente | Cada cor com mancha definida; overlap configurável |

A potência elétrica é a mesma (10 W); o ganho é **eficiência óptica aparente** — mesma corrente, mais lux onde importa.

## Especificação StageMod v1

| Parâmetro | Valor recomendado |
|---|---|
| Diâmetro lente | **20 mm** |
| Material | **PMMA** (acrílico óptico) |
| Ângulo de feixe | **90°** (fixo em todo o projeto) |
| Compatibilidade LED | Star **20 mm**, chip COB/LED central ~9–14 mm |
| Quantidade por módulo | **2** (uma em A, uma em B) |

### Busca para compra

| Item | Termos AliExpress / LCSC |
|---|---|
| Lente 90° | `20mm LED lens 90 degree PMMA` |
| Suporte | `20mm LED lens holder bracket` |
| Kit | `20mm lens + holder for 1W 3W 5W 10W LED` |

Verificar na ficha: diâmetro **20 mm**, altura total da lente **~10–12 mm**, diâmetro interno compatível com face emissiva do star 10 W.

## Montagem mecânica

### Stack típico (cada canal)

```
        ┌─────────────┐
        │ Lente 20 mm │  ← PMMA, face côncava/convexa para o LED
        ├─────────────┤
        │ Holder / anel│  ← nylon ou alumínio, prende na PCB ou heatsink
        ├─────────────┤
        │  Star 10 W  │  ← pasta térmica no heatsink
        ├─────────────┤
        │  Heatsink   │
        └─────────────┘
```

### Regras de montagem

| Regra | Motivo |
|---|---|
| **Folga 0,5–1,5 mm** entre dome do LED e lente | PMMA deforma > ~85 °C |
| Lente **não** encostar no phosphor/die | Hotspot e degradação |
| Holder fixado no **heatsink ou PCB**, não só na lente | Vibração em palco |
| Abertura frontal do módulo ≥ 20 mm por ótica | Não cortar o feixe |
| WW e Red podem usar **mesmo ângulo** (90°) | Simplifica estoque |

### Posição dos dois LEDs no módulo

```
Vista frontal (exemplo):

    ┌────────────────────────────┐
    │   (○) Lente A    (○) Lente B   │   ← centros ~28–32 mm
    │    WW 20mm        Red 20mm     │
    └────────────────────────────┘
```

- Centro a centro: **28–32 mm** (lentes 20 mm quase encostadas com borda mínima).
- Ambas as lentes em **90°**: overlap da mancha a **~1 m** ajuda wash unificado entre WW e vermelho.

## Ângulo de feixe: 90° (padrão único)

Todo módulo StageMod usa **somente lente 90°** nos canais A e B.

| Parâmetro | Valor |
|---|---|
| Ângulo | **90°** |
| Uso | Wash largo, parede, palco pequeno/médio |
| Distância típica | 1–2,5 m do módulo à superfície iluminada |
| Estoque | Comprar **apenas 90°** — simplifica montagem e reposição |

## Compatibilidade térmica

| Material | Tmax contínuo | Notas |
|---|---|---|
| PMMA | ~80–90 °C | OK com folga de ar e heatsink adequado |
| Silicone óptico | ~150 °C | Alternativa se lente encostar perto do LED |
| Vidro | Alto | Pesado, raro em 20 mm DIY |

Teste de aceite: 30 min @ 100 % PWM — lente não deve amolecer nem embacar permanentemente.

## Efeito na dissipação

A lente **não reduz** calor no star; o heatsink deve ser dimensionado igual (10 W/canal).

O holder pode ter **furos de ventilação** laterais para convecção entre star e lente.

## BOM por módulo (óptica)

| Qty | Item | ~US$ |
|-----|---|---|
| 2 | Lente PMMA 20 mm 90° | 0,40–0,80 |
| 2 | Holder / anel 20 mm | 0,30–0,60 |
| — | Parafuso M3 ou clip (se holder exigir) | 0,10 |
| | **Subtotal óptica / módulo** | **~1,00** |

## Integração na PCB (fase KiCad)

- Furos de fixação do holder alinhados ao star (padrão 20 mm star: 2× furo M3 ou 1× central).
- Silkscreen: círculo **Ø20** = zona da lente.
- Keep-out: altura **12 mm** acima do star para carcaça frontal.

## Reposição

Lente danificada: trocar por outra **90°** idêntica. Não alterar `modules.json`.

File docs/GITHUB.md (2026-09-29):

# Publicar no GitHub — `andreysenes/light`

Repositório: **https://github.com/andreysenes/light**

## Remote já configurado neste clone

```bash
git remote -v
# github  git@github.com:andreysenes/light.git
```

## Enviar o código (`main`)

### Opção A — sua máquina (SSH já no GitHub)

```bash
cd /caminho/do/projeto
git remote add github git@github.com:andreysenes/light.git   # se ainda não existir
git push -u github main
```

### Opção B — deploy key (Cloud Agent / CI)

1. Em GitHub → **Settings** → **Deploy keys** → **Add deploy key**
2. Título: `stagemod-light-deploy`
3. Cole a chave pública abaixo, marque **Allow write access**
4. No ambiente com a chave privada correspondente:

```bash
git push -u github main
```

Chave pública (deploy):

```
ssh-ed25519 AAAAC3NzaC1lZDI1NTE5AAAAICobvdZ+fGsXzpgxzBGd8n2IBgc9Vo86q4Yvb7GDAY9A stagemod-light-deploy
```

### Opção C — HTTPS + token

```bash
git push https://github.com/andreysenes/light.git main
# usuário: andreysenes | senha: Personal Access Token (repo scope)
```

## Espelhar `origin` (Cursor) e GitHub

```bash
git push origin main    # Cursor cloud
git push github main    # GitHub
```

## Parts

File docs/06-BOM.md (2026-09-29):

# BOM — v0

Componentes para **Medusa** (Pro Micro + ZS-040) + **4 módulos WS2812B** + tubo.

## Lista principal

| Qty | Item | Ref / busca | ~US$ | Notas |
|-----|---|---|---|---|
| 1 | Pro Micro 5V 16MHz | SparkFun / clone | 4–8 | Cabeça |
| 1 | **ZS-040** BLE UART | HM-10 / ZS-040 | 2–5 | MIDI sem fio → [19-ZS-040.md](19-ZS-040.md) |
| 4 | WS2812B | breakout ou LED star | 0,40 | 1 por módulo |
| 1 | Fonte 5V 10A + C14 | SMPS interna Medusa | 12–20 | Ver [17-CABECA-MEDUSA.md](17-CABECA-MEDUSA.md) |
| 6 | Resistor 470Ω | 1/4W | 0,30 | 4× módulos + 2× Medusa (D5/D6) |
| 5 | Capacitor 470µF–1000µF | 6,3V+ | 1,00 | 4× módulos + 1× Medusa |
| — | Fio silicone AWG22–24 | vermelho/preto/verde | 2 | Entre módulos |
| 1 | Cabo USB micro | — | — | Programar |
| | **Total** | | **~10–15** | |

## Cabeça Medusa (resumo)

| Item | Qty |
|---|-----|
| Pro Micro + **ZS-040** | 1 cada |
| Caixa ABS, C14, SMPS 5V 10A | 1 |
| XLR fêmea MOD/TUBO/INJ | 2–3 |
| 470 Ω (D5/D6) + 1000 µF barramento | 1 par |

## Opcional

| Item | Uso |
|---|-----|
| PCB perfurada | Fixar LEDs por módulo |
| Conector 3 pinos JST | Em vez de XLR entre módulos |
| AMS1117-3.3 | Só se ZS-040 for 3,3 V estrito |

## Por módulo (DIY)

| Item | Qty |
|---|-----|
| WS2812B | 1 |
| Resistor **470Ω** | 1 (DATA IN → DIN) |
| Capacitor **470µF–1000µF** | 1 (5V/GND no LED) |
| XLR IN + OUT (opc.) | 1 par |
| 3 fios (5V, GND, DATA) | pass-through + data série |

## O que não precisa na v0

| Item v1 | Motivo |
|---|---|
| ESP32 | Pro Micro basta |
| MAX485 / RJ45 | Cadeia WS2812 |
| P4 / 24V | LEDs são 5V |
| MOSFET / driver CC | Integrado no WS2812 |
| Lente 20mm | v1 |
| ATtiny | Sem MCU no módulo |

## Checklist antes de ligar

- [ ] 5V e GND corretos (nunca 24V)
- [ ] **470 Ω** no DATA IN de **cada** módulo (+ Medusa D5/D6)
- [ ] **Cap** 5V/GND em **cada** módulo (+ Medusa)
- [ ] Cadeia DIN→DOUT na ordem 1→2→3→4
- [ ] Boot pisca R,G,B,W nos 4 módulos
- [ ] ZS-040 pareado; MIDI BT ou USB testado ([19-ZS-040.md](19-ZS-040.md))

## Onde comprar

Guia detalhado com buscas no AliExpress: **[15-ALIEXPRESS-BOM.md](15-ALIEXPRESS-BOM.md)**

## v1 BOM

Rig 24V / 10W — [v1/README.md](v1/README.md).

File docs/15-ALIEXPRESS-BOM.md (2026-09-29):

# Guia de compras — AliExpress (StageMod v0)

Lista para montar o protótipo: **Pro Micro + 4 módulos WS2812B + tubo flexível + fonte 5V** + caixa [**Medusa**](17-CABECA-MEDUSA.md).

Links de busca (cole no AliExpress se o link não abrir):

| # | Peça | Busca no AliExpress |
|---|---|---|
| 1 | Pro Micro | `Pro Micro ATmega32U4 5V 16MHz` |
| 2 | WS2812B módulo (×4) | `WS2812B breakout board 5V DIN DOUT` |
| 3 | Tubo neon flex | `WS2812B neon tube 5V silicone` (já é fita addressable dentro do silicone) |
| 4 | Fonte 5V 10A (montar **dentro** da Medusa) | `5V 10A power supply SMPS switching` 100-240V |
| 4b | Entrada **C14** painel | `IEC320 C14 power inlet connector panel mount` |
| 4c | Cabo **C13** (se não tiver) | `C13 power cord` |
| 4d | Fusível 2A + base | `fuse holder 5x20mm 2A slow blow` |
| 5 | Resistor 470Ω | `470 ohm resistor 1/4W 100pcs` |
| 6 | Capacitor 1000µF | `1000uf 16V electrolytic capacitor` |
| 7 | Fio silicone | `silicone wire 22AWG red black green` |
| 8 | XLR fêmea painel ×3 (Medusa MOD/TUBO/INJ) | `XLR female 3 pin panel mount` |
| 9 | XLR macho painel ×4 (módulos OUT) + fêmea IN | `XLR male 3 pin panel mount` |
| 10 | ZS-040 BLE UART (Medusa) | `ZS-040 HM-10 bluetooth 4.0 serial` (breakout 5V se possível) |
| 11 | Caixa ABS + bornes | `ABS project box` + `terminal block 2 pin` |
| 12 | JST 3 pin (opcional) | `JST SM 3 pin connector cable` |

Documentação do módulo BT: **[19-ZS-040.md](19-ZS-040.md)**.

---

## ZS-040 — Bluetooth MIDI (Medusa) — obrigatório na cabeça

### O que buscar

```
ZS-040 HM-10 bluetooth 4.0 ble serial module
```

ou

```
CC2541 bluetooth module UART 5V
```

### Filtros

| Campo | Valor |
|---|---|
| Chip | **CC2541** / HM-10 compatível |
| Interface | **UART** (TX, RX, VCC, GND) |
| Tensão | **5 V** no breakout (preferido) ou 3,3 V |
| Firmware | Transparente serial (não precisa programar para v0) |

### Evitar

- Módulo só **SPP clássico** sem BLE (nomes genéricos “Bluetooth 2.0 audio”)
- Placa **sem** pinos TX/RX expostos

### Preço referência

| Qty | ~US$ |
|-----|---|
| 1 | 2–5 |
| 2 (reserva) | 4–8 |

### Após comprar

1. Configurar `AT+BAUD4` → **115200** (ver [19-ZS-040.md](19-ZS-040.md)).
2. Soldar na Medusa: TX→RX Pro Micro, RX←TX Pro Micro.
3. Parear no PC e testar com Hairless / bridge MIDI.

---

## 1. Pro Micro (cabeça) — obrigatório

### O que buscar

```
Pro Micro ATmega32U4 5V 16MHz bootloader
```

### Filtros no anúncio

| Campo | Valor correto |
|---|---|
| Chip | **ATmega32U4** (não ATmega328P = Pro Mini errado) |
| Voltagem | **5V** / 16MHz |
| USB | Micro-USB ou USB-C (tanto faz) |
| Bootloader | Com bootloader Arduino / Caterina |

### Evitar

- **Pro Mini** — não tem USB nativo, não serve para MIDI USB fácil
- **3.3V / 8MHz** — incompatível com WS2812B em 5V
- Placa sem foto do chip legível

### Preço referência

| Qty | ~US$ |
|-----|---|
| 1 | 3–6 |
| 2 (reserva) | 6–10 |

### Lojas com boa reputação (buscar pelo nome)

- Estardyn Official Store
- Worldchips
- HiLetgo (também vende no Ali)

### Arduino IDE

Placa: **Arduino Leonardo** ou **SparkFun Pro Micro**

---

## 2. WS2812B — 4 módulos spot

### Opção A — Breakout com PCB (recomendado)

```
WS2812B breakout 5V addressable LED module DIN DOUT
```

Ou:

```
10pcs WS2812B mini PCB board 5V 5050
```

| Verificar na foto | |
|---|---|
| 4 pinos | **5V, GND, DIN, DOUT** |
| Chip | WS2812B (não só WS2812 antigo) |
| Tensão | **5V** |

Pacote **10 peças** costuma sair ~US$ 1–3 — sobram para reserva.

### Opção B — Fita e cortar 4 pedaços

```
WS2812B LED strip 5V 60LED/m IP30 1 meter
```

- Cortar **4 LEDs** com tesoura nas linhas de corte
- Soldar fios em 5V / GND / DIN / DOUT de cada pedaço
- Alternativa barata se não quiser breakout com PCB

### Evitar

- WS2811 só (protocolo diferente no firmware)
- **12V** strip
- LED “RGB” comum **sem** chip integrado (não é addressable)

### Preço referência

| Item | ~US$ |
|---|---|
| 10× breakout | 1–4 |
| 1 m fita 60LED/m | 2–5 |

---

## 3. Tubo flexível neon (gradiente / chase)

O tubo neon **já inclui** a fita addressable dentro do silicone — **não precisa comprar fita separada**.

### O que buscar — tubo pronto

```
WS2812B neon LED tube 5V silicone IP67
```

Modelo do projeto: **D15-Woven Magic** (WS2811, 50 LED/m) — [detalhes](14-TUBO-FLEX.md#tubo-comprado-4-m--manual-d15-woven-magic).

### Filtros críticos

| Campo | Valor |
|---|---|
| Voltagem | **DC 5V** (não 12V) |
| Chip / IC | **WS2811** ou WS2812B (addressable) |
| LEDs/m | Anotar para `NUM_TUBE_LEDS` (ex.: **50** = 200 LEDs em 4 m) |

### Evitar

- Tubo **12V** ou **24V**
- Anúncio só “RGB LED tube” **sem** WS2812 / addressable
- Kit com controlador IR só — você usa o Pro Micro, não precisa do controle remoto (mas o tubo sozinho basta)

### Preço referência

| Item | ~US$ |
|---|---|
| Tubo neon 4 m 5V addressable | 15–40 |

---

## 4. Fonte 5V — obrigatório

### O que buscar

```
5V 10A power supply SMPS switching
```

### Filtros

| Campo | Valor |
|---|---|
| Saída | **5V DC** |
| Corrente | **≥ 5A** (tubo 4 m); **10A** recomendado |
| Entrada | **100–240V** (bivolt) |

Só 4 módulos sem tubo: **1A** basta.

### Evitar

- Fonte genérica “5V” sem amperagem na etiqueta
- USB charger de celular fraco (500 mA) para rig completo

### Preço referência

| Amperagem | ~US$ |
|---|---|
| 5V 1A | 2–4 |
| 5V 5A | 6–10 |
| 5V 10A | 10–18 |

---

## 5. Componentes passivos — obrigatório

### Resistor 470Ω (linha de data)

```
470 ohm resistor kit 1/4W
```

Mínimo **2 unidades** (D5 tubo + D6 módulos). Kit 100 pcs ~US$ 1.

### Capacitor eletrolítico 1000µF

```
1000uf 16V electrolytic capacitor
```

| Verificar | |
|---|---|
| Tensão | **≥ 10V** (16V comum) |
| Qty | 1–2 (um no tubo, um nos módulos) |

~US$ 0.50–2 (kit).

---

## 6. Fios e conectores — recomendado

### Fio silicone 22 AWG

```
silicone wire 22AWG 5 colors
```

| Cor sugerida | Uso |
|---|-----|
| Vermelho | 5V |
| Preto | GND |
| Verde/branco | DATA |

### JST 3 pinos (opcional, facilita desmontar módulos)

```
JST SM 3 pin connector male female cable
```

### Mini interruptor (opcional)

```
mini rocker switch 5x8mm 2 pin
```

Na linha 5V da fonte.

---

## Lista de compras mínima

| # | Item | Qty | ~US$ |
|---|---|-----|---|
| 1 | Pro Micro 5V 32U4 | 1–2 | 4 |
| 2 | WS2812B breakout ou 10pcs mini PCB | 4–10 | 2 |
| 3 | Tubo neon **5V** addressable (ex. 4 m D15) | 1 | — (já tem) |
| 4 | Fonte 5V **10A** + C14 | 1 | 15 |
| 4b | **ZS-040** (Medusa) | 1 | 3 |
| 5 | Resistor 470Ω | 6+ | 1 |
| 6 | Capacitor 1000µF 16V | 2 | 1 |
| 7 | Fio silicone 22AWG | 1 kit | 3 |
| | **Total estimado** (sem tubo/Pro Micro/LEDs) | | **~15–20** |

Envio Brasil: +US$ 0–15 dependendo do vendedor e promo “Choice” / “AliExpress Standard”.

---

## Checklist ao receber

### Pro Micro

- [ ] Chip marcado **ATmega32U4**
- [ ] Liga no USB; Arduino IDE reconhece porta COM
- [ ] Upload de sketch de teste OK

### WS2812B

- [ ] 4 pinos: 5V, GND, DIN, DOUT
- [ ] Acende com teste FastLED em um LED

### Tubo

- [ ] Etiqueta diz **5V** e chip addressable (**WS2811** no D15)
- [ ] Contar LEDs ou medir: atualizar `NUM_TUBE_LEDS` no `.ino`
- [ ] Teste com PC 7 (gradient wave)

### Fonte

- [ ] Multímetro: saída **5,0–5,2 V**
- [ ] C14 com terra ligado à carcaça SMPS

### ZS-040

- [ ] `AT` responde OK
- [ ] Baud **115200** (`AT+BAUD4`)
- [ ] Pareamento Bluetooth no PC

---

## Ordem de montagem sugerida

1. Pro Micro + **1** WS2812B (teste pin D6)
2. Adicionar módulos 2–4 em cadeia
3. Ligar tubo no **D5**; ajustar `NUM_TUBE_LEDS`
4. Fonte 5V 10A alimentando tudo (GND comum; injeção 5V no meio do tubo 4 m)

Firmware: [firmware/promicro-4mod/](../firmware/promicro-4mod/)

---

## v1 (futuro — não comprar ainda para v0)

ESP32-S3, fonte 24V, P4, RJ45, LEDs 10W — [v1/README.md](v1/README.md)

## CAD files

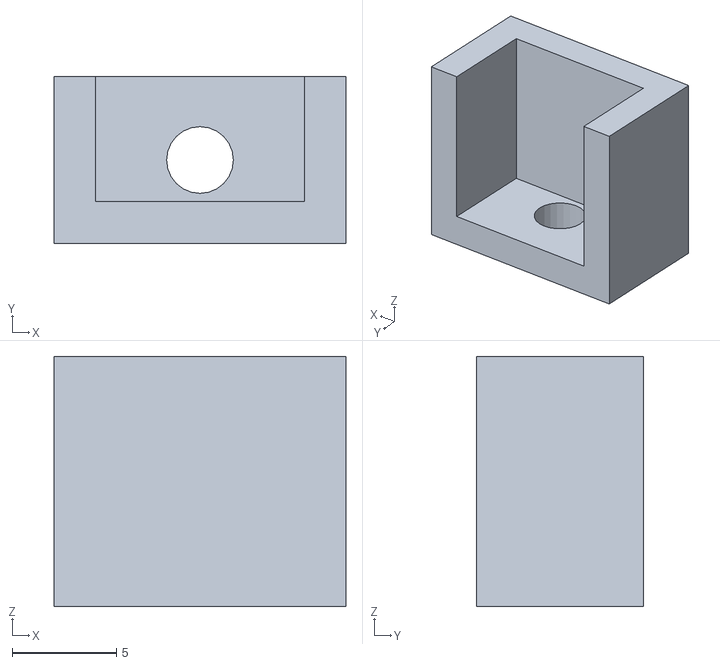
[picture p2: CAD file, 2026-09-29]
hardware/spot-module-v0/stl/spot_led_clip.stl
14.0 x 8.00 x 12.0

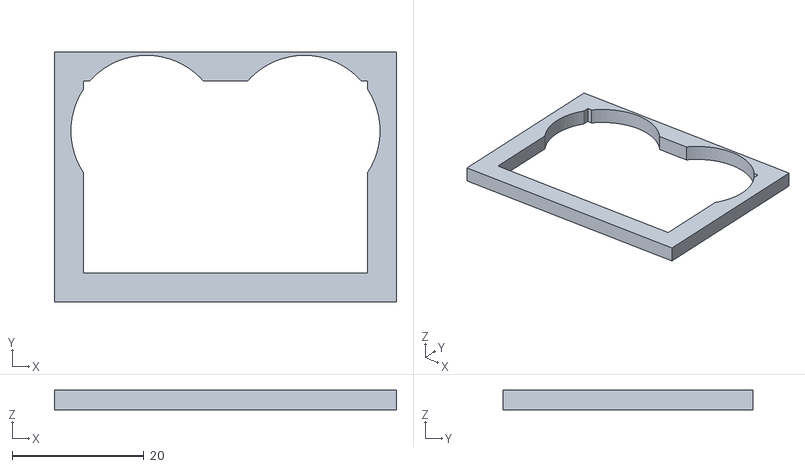
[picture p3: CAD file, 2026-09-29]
hardware/spot-module-v0/stl/spot_bottom_plate.stl
52.0 x 38.0 x 3.00

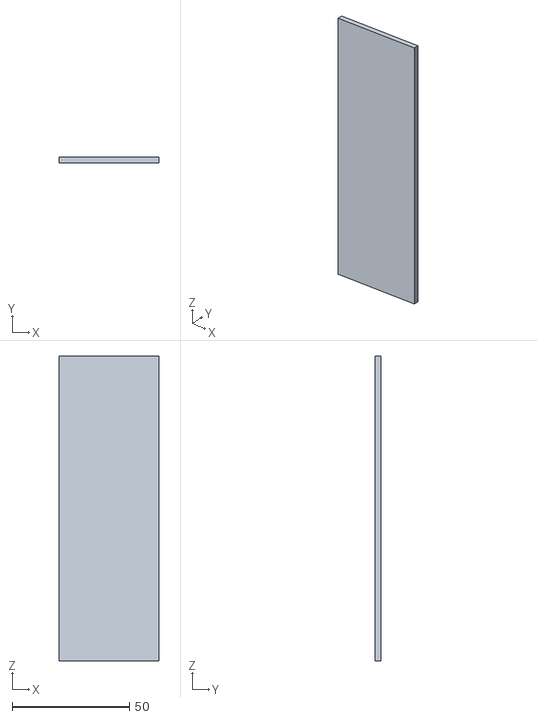
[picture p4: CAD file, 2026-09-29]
hardware/spot-module-v0/stl/spot_diffuser.stl
42.5 x 2.50 x 130.0

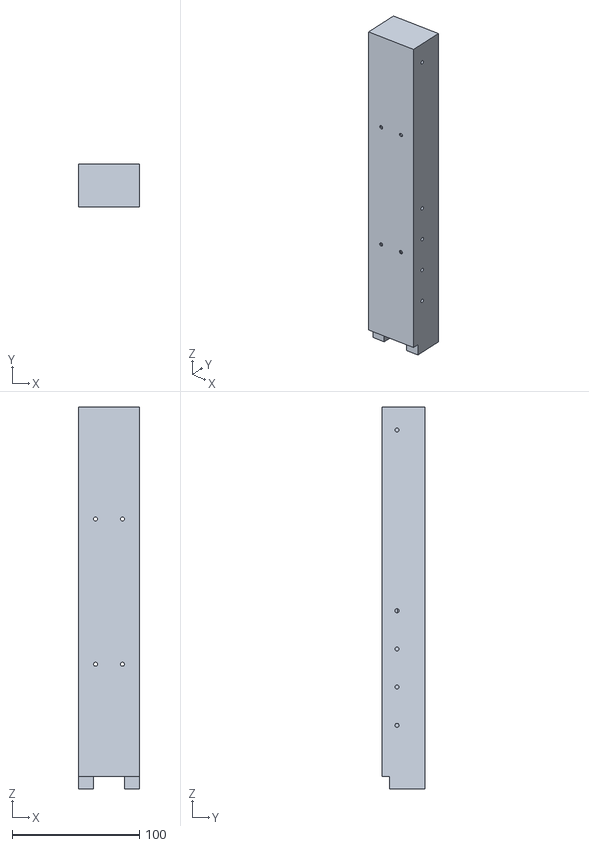
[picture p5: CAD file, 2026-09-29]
hardware/spot-module-v0/stl/spot_body.stl
48.0 x 34.0 x 300.0

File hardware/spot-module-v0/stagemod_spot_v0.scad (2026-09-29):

// StageMod v0 — módulo spot (corpo impresso 3D)
// Design: coluna em U, difusor frontal recuado, pés laterais, tampa inferior (XLR).
// Exportar: ./export-stl.sh  ou  openscad -D PART="body" -o stl/spot_body.stl stagemod_spot_v0.scad

PART = "preview"; // preview | body | diffuser | bottom_plate | led_clip

// --- Dimensões gerais (mm) ---
outer_w        = 48;      // largura frontal
outer_d        = 34;      // profundidade (frente → fundo)
total_h        = 300;     // altura total incluindo pés
wall           = 2.4;     // parede (FDM 0,4 mm × 6)
foot_h         = 10;      // altura dos pés
foot_w         = 12;      // largura de cada pé (parede lateral)
foot_front_gap = 6;       // pé não chega à frente (estética da referência)

// Difusor
diffuser_thick    = 2.5;
diffuser_recess   = 4.5;  // recuo em relação à borda frontal
diffuser_clear    = 0.35; // folga lateral

// LEDs (ajuste ao seu PCB / fita)
led_count      = 8;
led_pitch      = 10.0;    // centro a centro (mm) — fita 100 LED/m ≈ 10 mm
led_pcb_w      = 10.0;    // largura do breakout / fita
led_pcb_thick  = 2.0;

// Fixação
m3_hole_d      = 3.2;
m3_boss_od     = 6.5;
m3_boss_h      = 8;

// XLR painel (furo circular simplificado; ajuste ao conector real)
xlr_hole_d     = 23.0;
xlr_inset_y    = 10;      // do fundo da peça para o centro do furo

$fn = 48;

inner_w = outer_w - 2 * wall;
inner_d = outer_d - wall - diffuser_recess - diffuser_thick - 0.5;

led_strip_len = (led_count - 1) * led_pitch + led_pcb_w;
diffuser_h = led_strip_len + 50; // margem acima/abaixo do LED
diffuser_y0 = (total_h - foot_h - diffuser_h) / 2; // centrado na área útil

function screw_boss() =
  cylinder(h = m3_boss_h, d = m3_boss_od, $fn = 24);

module spot_feet() {
  for (x = [0, outer_w - foot_w])
    translate([x, foot_front_gap, 0])
      cube([foot_w, outer_d - foot_front_gap, foot_h], center = false);
}

module spot_shell_solid() {
  translate([0, 0, foot_h])
    cube([outer_w, outer_d, total_h - foot_h], center = false);
  spot_feet();
}

module inner_cavity() {
  // câmara interna (atrás do difusor)
  translate([wall, diffuser_recess + diffuser_thick + 0.2, foot_h + wall])
    cube([
      inner_w,
      inner_d,
      total_h - foot_h - 2 * wall - 3
    ], center = false);

  // slot frontal para o difusor
  translate([
    wall + diffuser_clear,
    wall * 0.5,
    foot_h + diffuser_y0
  ])
    cube([
      inner_w - 2 * diffuser_clear,
      diffuser_recess + diffuser_thick + 1,
      diffuser_h
    ], center = false);
}

module diffuser_screw_holes() {
  // dois parafusos na base do difusor (como na referência)
  for (z = [foot_h + diffuser_y0 + 8, foot_h + diffuser_y0 + diffuser_h - 8]) {
    for (x = [outer_w * 0.28, outer_w * 0.72]) {
      translate([x, outer_d / 2, z])
        rotate([90, 0, 0])
          cylinder(h = outer_d + 2, d = m3_hole_d, center = true);
    }
  }
}

module side_boss_holes() {
  // coluna de parafusos na lateral (decorativo / opcional reforço)
  for (z = [foot_h + 40, foot_h + 70, foot_h + 100, foot_h + 130]) {
    translate([outer_w - wall / 2, outer_d * 0.35, z])
      rotate([0, 90, 0])
        cylinder(h = wall + 4, d = m3_hole_d, center = true);
  }
  translate([outer_w - wall / 2, outer_d * 0.35, total_h - 18])
    rotate([0, 90, 0])
      cylinder(h = wall + 4, d = m3_hole_d, center = true);
}

module cable_exit() {
  translate([outer_w / 2, outer_d - wall - 1, foot_h + 6])
    rotate([90, 0, 0])
      cylinder(h = wall + 6, d = 7, center = true);
}

module body() {
  difference() {
    spot_shell_solid();
    inner_cavity();
    diffuser_screw_holes();
    side_boss_holes();
    cable_exit();
    // abertura para tampa inferior
    translate([wall + 2, wall + 2, foot_h - 0.01])
      cube([outer_w - 2 * wall - 4, outer_d - 2 * wall - 4, 3.5], center = false);
  }

  // calço interno para PCB de LEDs (centralizado na largura)
  led_x = outer_w / 2 - led_pcb_w / 2;
  led_z0 = foot_h + diffuser_y0 + (diffuser_h - led_strip_len) / 2;
  translate([led_x, diffuser_recess + diffuser_thick + 1.2, led_z0])
    cube([led_pcb_w, 4, led_strip_len], center = false);

  // canaleta de fios até a base
  translate([outer_w / 2 - 3, diffuser_recess + diffuser_thick + 1, foot_h])
    cube([6, inner_d * 0.6, led_z0 - foot_h + 5], center = false);
}

module diffuser_panel() {
  w = inner_w - 2 * diffuser_clear;
  translate([wall + diffuser_clear, 0, 0])
    cube([w, diffuser_thick, diffuser_h], center = false);
}

module bottom_plate() {
  plate_h = 3;
  difference() {
    translate([-2, -2, 0])
      cube([outer_w + 4, outer_d + 4, plate_h], center = false);
    // encaixe no corpo
    translate([wall, wall, -0.01])
      cube([outer_w - 2 * wall, outer_d - 2 * wall, plate_h + 0.5], center = false);
    // XLR IN (esquerda) e OUT (direita) — vista de baixo, frente = +Y
    for (x = [outer_w * 0.25, outer_w * 0.75]) {
      translate([x, outer_d - xlr_inset_y, -0.01])
        cylinder(h = plate_h + 2, d = xlr_hole_d, $fn = 64);
    }
    // furos M3 na tampa → corpo
    for (xy = [[8, 8], [outer_w - 8, 8], [8, outer_d - 8], [outer_w - 8, outer_d - 8]]) {
      translate([xy[0], xy[1], -0.01])
        cylinder(h = plate_h + 2, d = m3_hole_d, $fn = 24);
    }
    translate([outer_w / 2, outer_d / 2, -0.01])
      cylinder(h = plate_h + 2, d = 8, $fn = 32); // passagem cabos
  }
}

module led_clip() {
  // Clipe opcional (2×) para prender fita LED — imprimir se não usar calço integrado
  difference() {
    cube([led_pcb_w + 4, 8, 12], center = false);
    translate([2, 2, 2])
      cube([led_pcb_w, 6, 10], center = false);
    translate([led_pcb_w / 2 + 2, 4, -0.01])
      cylinder(h = 3, d = m3_hole_d, $fn = 24);
  }
}

module preview() {
  color("Gainsboro") body();
  translate([wall + diffuser_clear, -diffuser_recess - diffuser_thick, foot_h + diffuser_y0])
    color("White", 0.85) diffuser_panel();
  translate([0, 0, -3])
    color("DimGray") bottom_plate();
}

if (PART == "body") body();
else if (PART == "diffuser") diffuser_panel();
else if (PART == "bottom_plate") bottom_plate();
else if (PART == "led_clip") led_clip();
else preview();

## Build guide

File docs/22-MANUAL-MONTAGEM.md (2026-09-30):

# Manual de montagem e soldagem — StageMod v0

Guia passo a passo para montar **Medusa** (Pro Micro + ZS-040 + fonte), **4 módulos** (8× WS2812B cada) e **tubo 4 m**.

Este manual usa ligação **direta** de fios (5 V, GND, DATA) — **sem resistor nem capacitor** no texto de montagem.

| Referência | Documento |
|---|---|
| Pinagem XLR | [16-XLR-CONECTORES.md](16-XLR-CONECTORES.md) |
| ZS-040 | [19-ZS-040.md](19-ZS-040.md) |
| Firmware | [firmware/promicro-4mod/](../firmware/promicro-4mod/) |
| O que já temos | [20-INVENTARIO-HARDWARE.md](20-INVENTARIO-HARDWARE.md) |

---

## Ordem de montagem (siga nesta sequência)

```
1. FONTE     — SMPS 5 V, barramento, C14 (AC por último na caixa)
2. PRO MICRO — Medusa: placa, ZS-040, XLR no painel, D5/D6
3. CABOS     — 4× módulo spot + tentáculos XLR + tubo
4. TESTE     — continuidade e 5 V (ainda sem firmware)
5. FIRMWARE  — upload, ZS-040, boot e MIDI
```

Detalhes em cada seção abaixo. **Ferramentas** e **convenções** vêm antes da Parte 1.

---

## Ferramentas

| Ferramenta | Uso |
|---|-----|
| Ferro de solda **25–60 W**, ponta fina | Conectores, fios, pads |
| Estanho com fluxo | Ligações |
| Alicate de corte / decapador AWG 18–22 | Cabos |
| Multímetro | Continuidade, 5 V, polaridade |
| Chave fenda / furadeira | Painel (C14, XLR, USB) |
| Estilete, fita, etiquetas | Identificar cabos `MOD`, `TUBO`, `DATA` |

EPI: óculos, local ventilado. Para **127/220 V**, tomada **desligada** e caixa **aberta** só até validar o DC.

---

## Convenções de fio e XLR

### Cores sugeridas

| Cor | Sinal |
|-----|---|
| Vermelho | **+5 V** |
| Preto | **GND** |
| Verde ou branco | **DATA** |

### XLR 3 pinos (todos os cabos do projeto)

| Pino | Sinal |
|---|---|
| **1** | GND (ligar **shell** do conector ao GND) |
| **2** | +5 V |
| **3** | DATA |

Etiqueta nos cabos: **`5V PIXEL — NÃO É ÁUDIO`**.

### Pro Micro (pinos úteis)

| Pro Micro | Função |
|---|---|
| **VCC** | +5 V |
| **GND** | Terra |
| **D6** | DATA → cadeia dos **módulos** |
| **D5** | DATA → **tubo** |
| **D0 (RX)** | ← TX do ZS-040 |
| **D1 (TX)** | → RX do ZS-040 |
| **USB** | Programação + MIDI com cabo |

---

## Parte 1 — Fonte

Objetivo: **5 V estáveis** no barramento da Medusa, com segurança na entrada AC.

### 1.1 Mecânica da caixa

1. Furar painel: **C14**, **USB micro**, XLR **MOD**, XLR **TUBO** (e **INJ** se usar).
2. Parafusar **fonte SMPS 5 V 10 A** na caixa (espaçadores; não encostar lâmina metálica viva no fundo sem isolamento).

### 1.2 Barramento DC (primeiro em bancada, se quiser)

Pode testar a fonte **fora da caixa** com bornes antes de soldar na Medusa:

1. Saída **+V / −V** da SMPS → fio **AWG 18** vermelho (+) e preto (GND) até um ponto de distribuição.
2. **Não** ligar LEDs nem Pro Micro ainda — só medir **5,0–5,2 V** entre + e GND.

### 1.3 Entrada AC (C14)

**Somente** com caixa desenergizada e fios AC isolados.

1. **C14** → fonte SMPS:
   - **⏚** C14 → **FG** da fonte
   - **N** → **N**
   - **L** → **fusível 2 A** → **L** da fonte
2. Multímetro: **sem curto** entre L e N, entre L e ⏚.
3. Etiquetar **127/220 V** na caixa.

**Primeira energização na rede:** sem cabos XLR nos módulos; medir de novo **5 V** no barramento. Fechar a tampa só depois de validar o DC.

### 1.4 Derivações do barramento (ainda sem dados)

Do mesmo **+5 V / GND**, preparar fios para (soldar na Parte 2):

- **Pino 2** e **pino 1** dos XLR **MOD**, **TUBO** (e **INJ**)
- **VCC** / **GND** do Pro Micro e do ZS-040
- **Shell** de cada XLR → **GND**

---

## Parte 2 — Pro Micro (Medusa)

Objetivo: placa e Bluetooth na caixa, **alimentados pelo barramento**, saídas de dados nos XLR. **Ainda não** fazer upload do firmware.

> No StageMod v0 a “placa” é o **Pro Micro** (ATmega32U4, 5 V) — não o Raspberry Pi Pico. O firmware do repositório é só para Pro Micro.

### 2.1 Ligar a fonte no Pro Micro

Use a **mesma** fonte **5 V** da Parte 1 (barramento vermelho = +, preto = GND).

```
Fonte 5 V (+) ────────► pad VCC  (ou pin "VCC" / "5V" na borda)
Fonte 5 V (−) ────────► pad GND  (qualquer GND na borda)
```

| Passo | Ação |
|---|---|
| 1 | Fonte **desligada** na tomada (ou SMPS sem AC). |
| 2 | Multímetro na saída da fonte: **vermelho** no **+V**, **preto** no **−V** → deve marcar **+5 V** (não invertido). |
| 3 | Soldar ou parafusar fio **AWG 22–18** do **+ barramento** no **VCC** do Pro Micro. |
| 4 | Fio do **GND barramento** no **GND** do Pro Micro (mesmo plano de terra da fonte). |
| 5 | **Não** alimentar o Pro Micro pelo pino **RAW** com 5 V — **RAW** é entrada para o regulador interno (7–12 V em muitas clones). Com SMPS 5 V use só **VCC**. |
| 6 | Ligar a fonte: a placa não acende LEDs sozinha ainda; opcional: LED de power da clone aceso. Medir **5 V** entre VCC e GND nos pads. |
| 7 | **USB:** pode ficar desconectado nesta etapa. Depois, para programar, USB + fonte 5 V no **VCC** é o uso normal na Medusa (clone com diodo entre USB e VCC). |

**O que não fazer**

- Não passar a **corrente dos LEDs** pelo Pro Micro — só **sinal** em D5/D6; **5 V dos módulos/tubo** vão direto do barramento aos XLR (pino 2).
- Não ligar **+5 V** em **GND** (confira cores antes de energizar).

### 2.2 Fixar placa na caixa

1. Fixar **Pro Micro** com espaçadores (USB acessível pelo painel).
2. Repetir o par **VCC / GND** ao barramento se ainda não soldou na etapa 2.1.

### 2.3 ZS-040

| De | Para |
|----|---|
| ZS-040 **TX** | Pro Micro **D0 (RX)** |
| ZS-040 **RX** | Pro Micro **D1 (TX)** — adaptação 3,3 V se necessário: [19-ZS-040.md](19-ZS-040.md) |
| **GND** | GND comum |
| **VCC** | +5 V (se o módulo aceitar 5 V) |

A configuração **AT+BAUD4** (115200) fica na **Parte 5 — Firmware**.

### 2.4 XLR na Medusa (ligados ao Pro Micro)

Na caixa da Medusa você monta **2× XLR fêmea painel** (receptáculo): um etiquetado **MOD**, outro **TUBO**. O cabo de palco usa **plug macho** na ponta que encaixa na Medusa.

**Não é áudio** — pinagem de pixel (5 V / GND / DATA). Detalhes: [16-XLR-CONECTORES.md](16-XLR-CONECTORES.md).

#### O que vai em cada pino (os dois XLR iguais na alimentação)

| Pino XLR | Sinal | De onde vem na Medusa |
|---|---|---|
| **1** | **GND** | Barramento **GND** (preto AWG 18) + **shell** do conector |
| **2** | **+5 V** | Barramento **+5 V** (vermelho AWG 18) — **direto da fonte**, não pelo Pro Micro |
| **3** | **DATA** | Só **um** fio AWG 22 por XLR — ver tabela abaixo |

| XLR painel | Pino 3 (DATA) no Pro Micro |
|---|---|
| **MOD** | **D6** |
| **TUBO** | **D5** |

Ligação **direta** D5/D6 → pino 3 (sem resistor no manual v0).

#### Vista do conector (lado solda, padrão Neutrik / clone)

Olhando a **parte traseira** do XLR fêmea painel (onde solda), pinos em triângulo:

```
        pino 1 (GND)
           ●
    pino 2 ●   ● pino 3 (DATA)
      (+5V)
```

Confirme no **seu** conector com o datasheet — alguns clones marcam 1/2/3 no plástico.

#### Passo a passo — um XLR (repetir para MOD e TUBO)

| # | Ação |
|---|---|
| 1 | Furo no painel conforme o conector (geralmente **~24 mm** + 2 furos M3 ou presilha). Parafusar o XLR **antes** de soldar os fios longos. |
| 2 | **Shell / corpo metálico** → fio preto ao **GND** do barramento (ou aba de terra do conector). |
| 3 | **Pino 1** → mesmo **GND** (pode juntar shell + pino 1 num único ponto na caixa). |
| 4 | **Pino 2** → **+5 V** do barramento (fio vermelho AWG 18). |
| 5 | **Pino 3** → fio verde/branco AWG 22 até o pad **D6** (MOD) ou **D5** (TUBO) do Pro Micro. |
| 6 | **GND comum:** um fio preto AWG 22 do **GND** do Pro Micro ao mesmo ponto GND dos XLR (terra único na caixa). |
| 7 | Etiqueta no painel: `MOD D6` e `TUBO D5` + `5V PIXEL`. |

#### Esquema interno da Medusa

```
Barramento +5V ─────┬──── pino 2  XLR MOD
                    ├──── pino 2  XLR TUBO
                    ├──── VCC Pro Micro
                    └──── VCC ZS-040 (se 5 V)

Barramento GND ─────┬──── pino 1 + shell  XLR MOD
                    ├──── pino 1 + shell  XLR TUBO
                    ├──── GND Pro Micro
                    └──── GND ZS-040

Pro Micro D6 ────────────── pino 3  XLR MOD   ──cabo──► Mod1 IN
Pro Micro D5 ────────────── pino 3  XLR TUBO  ──cabo──► tubo
```

#### Cabo que sai da Medusa (primeiro tentáculo)

Não confundir com o XLR **dentro** da caixa: o **cabo** é montado à parte (Parte 3.2).

| Condutor no cabo | Cor sugerida | XLR macho na ponta da Medusa |
|---|---|---|
| GND | preto + malha | **pino 1** |
| +5 V | vermelho | **pino 2** |
| DATA | verde/branco | **pino 3** |

O plug **macho** do cabo entra no XLR **fêmea** do painel; na outra ponta, outro XLR (geralmente **fêmea** no cabo indo ao MOD 1 **IN** fêmea — use cabo **macho–macho** ou **macho–fêmea** conforme o que fechar a cadeia; o importante é **1=GND, 2=5V, 3=DATA** em todo o sistema).

#### Teste antes do firmware

Com fonte ligada e **sem** sketch no Pro Micro:

- Entre **pino 2 e 1** de cada XLR: **~5 V**
- Entre **pino 3 e 1**: não deve ser curto com +5 V; tensão flutuante é normal

---

## Parte 3 — Cabos

Objetivo: módulos spot prontos e cabos de palco até a Medusa.

### 3.1 Módulo spot WS2812B (repetir ×4, etiquetar MOD 1…4)

Cada módulo tem **8 LEDs WS2812B em série** (uma única linha de dados). No MIDI, **um módulo** = **8 pixels** com a **mesma cor** (CC RGB do módulo).

**Carcaça 3D (opcional):** montar LEDs primeiro, depois fechar com [23-MODULO-SPOT-3D.md](23-MODULO-SPOT-3D.md).

#### Conectores no corpo do módulo

| Lado | Conector | Cabo que encaixa |
|---|---|---|
| **IN** (entrada da cadeia) | XLR **fêmea** painel | Plug **macho** vindo da Medusa ou do módulo anterior |
| **OUT** (saída) | XLR **macho** painel | Próximo cabo segue para o **IN** do próximo módulo |

#### Formas físicas comuns

| Tipo | Montagem |
|---|---|
| **Placa/fita já com 8 LEDs** | Respeitar setas **DIN → DOUT** na PCB; soldar só os 3 fios nos XLR |
| **8× breakout** (estrela) | Trilha **5 V** e **GND**; encadear **DOUT → DIN** na ordem 1→8 |
| **Recorte de fita 60/100 LED/m** | Contar **8 pixels**; não cortar no meio de um LED; **DIN** no primeiro pixel do recorte |

Polaridade nos breakouts: **5V**, **GND**, **DIN** (entrada), **DOUT** (saída). **Nunca** trocar DIN com DOUT.

#### Esquema elétrico (um módulo)

```
  XLR IN (F)                         8× WS2812B em cadeia          XLR OUT (M)
  Pin 1 GND ────────┬── GND de todos os LEDs ─────────────────── Pin 1 GND
  Pin 2 5V  ────────┬── 5V de todos os LEDs ─────────────────── Pin 2 5V
  Pin 3 DATA ───────┼──► DIN (LED 1) … DOUT→DIN … LED 8 DOUT ─── Pin 3 DATA
```

**5 V e GND** passam **em paralelo** (IN → OUT). **DATA** entra no LED 1 e sai do LED 8.

#### Passo a passo — soldagem (×4 módulos)

| # | Ação |
|---|---|
| 1 | Fixar **XLR IN (fêmea)** e **XLR OUT (macho)** no painel do módulo (ou na tampa 3D). |
| 2 | **Shell** de cada XLR → fio **GND** comum no módulo. |
| 3 | **Pino 1** (IN e OUT) → mesma trilha **GND**; ligar **GND** de **todos** os LEDs. |
| 4 | **Pino 2** (IN e OUT) → mesma trilha **+5 V**; ligar **5V** de **todos** os LEDs. |
| 5 | **Pino 3 IN** → **DIN** do **1º** LED da cadeia (pixel que recebe dados da Medusa). |
| 6 | Ligar **DOUT** do LED *n* ao **DIN** do LED *n+1* até o **8º**. |
| 7 | **DOUT** do **8º** LED → **pino 3 OUT**. |
| 8 | Curto entre **pino 1↔1** e **pino 2↔2** do IN e OUT (pass-through), se não for um único fio contínuo. |
| 9 | Etiqueta **MOD 1** … **MOD 4** na parte de trás; foto dos pinos 1/2/3 para referência. |

Ordem dos 8 LEDs na coluna: use a **seta da fita** ou o silk **DIN** no primeiro — o firmware assume MOD 1 = pixels 0–7 na ordem em que a data percorre os LEDs.

#### Cadeia no palco (4 módulos)

```
Medusa XLR MOD ──► MOD 1 IN ──OUT► MOD 2 IN ──OUT► MOD 3 IN ──OUT► MOD 4 IN
     (D6)              (8 LED)         (8 LED)         (8 LED)         (8 LED)
```

| Etiqueta | Pixels no firmware | Nota MIDI |
|---|---|---|
| **MOD 1** | 0–7 | C3 |
| **MOD 2** | 8–15 | D3 |
| **MOD 3** | 16–23 | E3 |
| **MOD 4** | 24–31 | F3 |

- **DATA:** só **OUT → IN** entre módulos (série).  
- **5 V / GND:** a fonte na Medusa alimenta todos em **paralelo** pelos cabos XLR (pinos 1 e 2).

#### Teste de **um** módulo (após firmware na Medusa)

1. Só o cabo **Medusa MOD → MOD 1 IN** (MOD 2–4 desconectados).  
2. Boot: os **8 LEDs** do MOD 1 devem piscar **R → G → B → W** juntos.  
3. Acrescentar MOD 2, depois 3, depois 4; a sequência de boot percorre cada bloco de 8.

#### Erros comuns

| Problema | Causa usual |
|---|---|
| Módulo inteiro apagado | Sem 5 V no pino 2; GND aberto; IN/OUT trocados na cadeia |
| Só o 1º LED acende | Quebra na cadeia **DOUT→DIN** entre LED 2…8 |
| Cores trocadas | Ordem GRB no firmware — ver [02-LEDS-E-OPTICA.md](02-LEDS-E-OPTICA.md) |
| MOD 3 não responde | Cabo DATA saltou módulo; conferir **OUT** do MOD 2 → **IN** do MOD 3 |

### 3.2 Cabos XLR (tentáculos)

Pinagem em todos: **1=GND, 2=5V, 3=DATA**.

| Cabo | De | Para | Comprimento típico |
|---|-----|---|---|
| A | Medusa **MOD** | MOD 1 **IN** | 1–2 m |
| B–D | MOD **OUT** | próximo **IN** | 0,3–1 m |
| E | Medusa **TUBO** | tubo | 3–5 m |

**Tubo 4 m (200 LED):** vermelho = 5 V, fio do **meio** = DATA (WS2811), externo = GND (manual D15); ligar ao XLR 1/2/3.

Opcional: **5 V/GND** no **meio** do tubo para queda de tensão.

### 3.3 Ligação completa (visão geral)

```
[C13 rede] → C14 → SMPS 5V10A
                    ├─ Pro Micro + ZS-040
                    ├─ XLR MOD ──cabo──► MOD1 ⇄ MOD2 ⇄ MOD3 ⇄ MOD4
                    └─ XLR TUBO ──cabo──► Tubo 4m (200 LED)
```

---

## Parte 4 — Teste (antes do firmware)

Objetivo: confirmar **fiação e alimentação** sem depender do programa ainda.

| # | Procedimento | OK se |
|---|---|---|
| 1 | **Sem** Pro Micro no USB, barramento **sem** cargas pesadas | 5,0–5,2 V no barramento |
| 2 | Continuidade: XLR **pino 1** ↔ shell ↔ GND Medusa | bip no multímetro |
| 3 | Cada tentáculo: pino 2 ↔ pino 1 **não** curto; pino 2 = +5 V com fonte ligada | sem faísca, ~5 V |
| 4 | MOD 1 **só** no XLR MOD (Pro Micro ainda **sem** sketch) | 5 V nos pinos 2/1 do módulo; DATA isolada |
| 5 | Ordem física etiquetada MOD 1→4; tubo separado no XLR TUBO | cabos corretos |

Se algo falhar, corrija solda antes da Parte 5. LEDs **não** devem acender nesta fase (normal).

---

## Parte 5 — Firmware

Objetivo: programar o Pro Micro, Bluetooth e validar o rig completo.

### 5.1 Upload

1. Cabo **USB** no Pro Micro (placa **Leonardo / 5 V 16 MHz** no Arduino IDE).
2. Abrir [firmware/promicro-4mod/promicro-4mod.ino](../firmware/promicro-4mod/promicro-4mod.ino).
3. Conferir `LEDS_PER_MODULE 8`, `NUM_TUBE_LEDS 200`.
4. Upload.

### 5.2 ZS-040

1. Configurar **AT+BAUD4** (115200) — ver [19-ZS-040.md](19-ZS-040.md).
2. Parear com o PC; bridge MIDI→serial na mesma baud — [18-WIRELESS-MIDI.md](18-WIRELESS-MIDI.md).

### 5.3 Testes funcionais

| # | Teste | Esperado |
|---|---|---|
| 1 | Boot sem MIDI, **só MOD 1** ligado | 8 LEDs R → G → B → W |
| 2 | Cadeia MOD 1→4 | Cada módulo 8 LEDs na sequência de boot |
| 3 | Tubo no XLR TUBO | Animação curta após os módulos |
| 4 | CC 1–3 | MOD 1 muda cor (8 LEDs juntos) |
| 5 | Notas C3–F3 | Módulos 1–4 com velocity |
| 6 | CC 7 / PC | Dimmer e gradiente no tubo |
| 7 | BT vs USB | Um caminho MIDI por vez na DAW |

Brilho no início: **CC 7** ~30–40%.

```
DAW → Bluetooth → ZS-040 → Serial1
   ou USB → Pro Micro
```

---

## Soldagem — boas práticas

- Aquecer **metal + fio**, depois estanho; evitar bola seca no plástico do XLR.
- Tracionar levemente o fio após soldar no pino XLR.
- Não aquecer o **Pro Micro** mais de **3–4 s** por pad.
- WS2812B: não inverter **DIN/DOUT** na cadeia dos 8 LEDs.
- Foto da traseira dos XLR (pinos 1/2/3) em cada módulo.

---

## Problemas comuns

| Sintoma | Verificar |
|---|---|
| Módulo apagado | 5 V no pino 2; ordem MOD 1→4; DIN no 1º LED |
| Só 1º LED acende | DOUT→DIN entre os 8 LEDs |
| Cores erradas no tubo | `TUBE_COLOR_ORDER` no `.ino` |
| MIDI BT não chega | Baud 115200; COM do bridge; canal 1 |
| Tubo fraco no fim | Injeção 5 V/GND no meio dos 4 m |
| Pro Micro não aparece USB | Cabo dados; placa Leonardo 5V 16MHz |

---

## Checklist antes do show

- [ ] Etiquetas MOD 1–4 e cabos MOD/TUBO
- [ ] Firmware `LEDS_PER_MODULE 8`, `NUM_TUBE_LEDS 200`
- [ ] ZS-040 pareado; cabo USB reserva
- [ ] C14, fusível e XLR apertados
- [ ] Cabo C13 com terra da instalação

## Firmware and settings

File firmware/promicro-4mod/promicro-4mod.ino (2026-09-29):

/*
 * StageMod v0 — Pro Micro
 * - 4× módulos spot, 8× WS2812B cada (32 pixels, pin 6)
 * - Tubo D15-Woven Magic WS2811 (gradiente / chase, pin 5)
 *
 * Bibliotecas: MIDI Library (FortySevenEffects), FastLED
 *
 * MIDI: USB (cabo perto do PC) + Serial1 (ZS-040 na Medusa) — docs/18-WIRELESS-MIDI.md
 */

#include <MIDI.h>
#include <SerialMIDI.h>
#include <FastLED.h>

// 1 = MIDI USB. Cabeça perto do PC: plugar USB na Medusa.
#define ENABLE_USB_MIDI     1
// 1 = MIDI na UART (ZS-040 BLE). Palco sem cabo USB.
#define ENABLE_SERIAL_MIDI  1
// Igual ao ZS-040: 115200 após AT+BAUD4; ou 9600 padrão de fábrica
#define SERIAL_MIDI_BAUD    115200

// --- Módulos spot: 4 blocos × 8 WS2812B em cadeia (32 pixels) ---
#define MODULE_PIN        6
#define NUM_MODULES       4
#define LEDS_PER_MODULE   8
#define NUM_MODULE_PIXELS (NUM_MODULES * LEDS_PER_MODULE)

// --- Tubo D15-Woven Magic (manual: IC WS2811, 50 LED/m, corte 20 mm) ---
#define TUBE_PIN      5
#define NUM_TUBE_LEDS 200   // 4 m × 50 LED/m

#define MODULE_LED_TYPE   WS2812B
#define MODULE_COLOR_ORDER GRB
#define TUBE_LED_TYPE     WS2811
#define TUBE_COLOR_ORDER  RGB   // se cores invertidas, trocar para GRB

#define MIDI_NOTE_MODULE_1  60
#define MIDI_CHANNEL        1

CRGB modules[NUM_MODULE_PIXELS];
CRGB tube[NUM_TUBE_LEDS];

uint8_t moduleR[NUM_MODULES];
uint8_t moduleG[NUM_MODULES];
uint8_t moduleB[NUM_MODULES];

#if ENABLE_USB_MIDI
MIDI_CREATE_DEFAULT_INSTANCE();
#endif

#if ENABLE_SERIAL_MIDI
MIDI_CREATE_INSTANCE(SerialMIDI<Serial1>, MIDI_Serial);
#endif

uint8_t masterBrightness = 255;

// --- Tubo: estado e efeitos ---
enum TubeEffect : uint8_t {
  TUBE_OFF = 0,
  TUBE_CHASE = 1,          // cometa com rastro
  TUBE_GRADIENT_WAVE = 2,  // ondas de luz de larguras variadas ( ---  --  - )
  TUBE_RAINBOW = 3,        // gradiente arco-íris estático no tubo
  TUBE_SOLID = 4,
};

TubeEffect tubeEffect = TUBE_OFF;
uint8_t tubeHue = 160;
uint8_t tubeSpeed = 80;       // 0–255
uint8_t tubeDensity = 64;     // comprimento das “manchas” de luz
uint8_t tubeSolidBrightness = 200;

uint16_t tubeAnimOffset = 0;
uint8_t chaseHead = 0;
unsigned long lastAnimMs = 0;

static const uint8_t CC_RGB_MAP[][3] = {
  { 1,  2,  3  },
  { 4,  5,  6  },
  { 9,  10, 11 },
  { 12, 13, 14 },
};

// Tubo: CC 15=efeito 16=matiz 17=velocidade 18=densidade 19=brilho sólido
#define CC_TUBE_EFFECT   15
#define CC_TUBE_HUE      16
#define CC_TUBE_SPEED    17
#define CC_TUBE_DENSITY  18
#define CC_TUBE_SOLID_BRI 19

uint8_t midiToByte(byte value) {
  return (uint8_t)map(value, 0, 127, 0, 255);
}

void showAll() {
  FastLED.show();
}

void fillModulePixels(int index, CRGB color) {
  if (index < 0 || index >= NUM_MODULES) return;
  int base = index * LEDS_PER_MODULE;
  for (int i = 0; i < LEDS_PER_MODULE; i++) {
    modules[base + i] = color;
  }
}

void applyModuleColor(int index) {
  fillModulePixels(index, CRGB(moduleR[index], moduleG[index], moduleB[index]));
}

void applyModuleColorScaled(int index, uint8_t scale) {
  if (index < 0 || index >= NUM_MODULES) return;
  fillModulePixels(index, CRGB(
    (uint8_t)((uint16_t)moduleR[index] * scale / 255),
    (uint8_t)((uint16_t)moduleG[index] * scale / 255),
    (uint8_t)((uint16_t)moduleB[index] * scale / 255)
  ));
}

void tubeBlackout() {
  fill_solid(tube, NUM_TUBE_LEDS, CRGB::Black);
}

// Cometa: cabeça brilhante + rastro que apaga
void renderTubeChase() {
  tubeBlackout();
  uint8_t tailLen = map(tubeDensity, 0, 255, 2, 12);

  for (uint8_t t = 0; t < tailLen; t++) {
    int pos = (int)chaseHead - t;
    if (pos < 0) pos += NUM_TUBE_LEDS;
    if (pos >= NUM_TUBE_LEDS) pos -= NUM_TUBE_LEDS;

    uint8_t bri = 255 - (uint8_t)((uint16_t)t * 255 / tailLen);
    tube[pos] = CHSV(tubeHue, 255, bri);
  }
}

// Ondas de brilho — cria manchas de tamanhos diferentes que se movem:
// visual:  ------    --   ---   -     -----
void renderTubeGradientWave() {
  uint8_t freq = map(tubeDensity, 0, 255, 8, 48);

  for (int i = 0; i < NUM_TUBE_LEDS; i++) {
    uint16_t phase = (uint16_t)i * freq + tubeAnimOffset;
    uint8_t wave = sin8((uint8_t)(phase & 0xFF));
    // Segunda harmônica para variar largura dos “traços”
    uint8_t wave2 = sin8((uint8_t)((phase * 2) & 0xFF));
    uint8_t bri = (uint8_t)((uint16_t)wave * wave2 / 255);
    tube[i] = CHSV(tubeHue, 220, bri);
  }
}

void renderTubeRainbow() {
  for (int i = 0; i < NUM_TUBE_LEDS; i++) {
    uint8_t hue = (uint8_t)((uint16_t)i * 255 / NUM_TUBE_LEDS + tubeHue);
    tube[i] = CHSV(hue, 255, 200);
  }
}

void renderTubeSolid() {
  fill_solid(tube, NUM_TUBE_LEDS, CHSV(tubeHue, 255, tubeSolidBrightness));
}

void renderTube() {
  switch (tubeEffect) {
    case TUBE_OFF:
      tubeBlackout();
      break;
    case TUBE_CHASE:
      renderTubeChase();
      break;
    case TUBE_GRADIENT_WAVE:
      renderTubeGradientWave();
      break;
    case TUBE_RAINBOW:
      renderTubeRainbow();
      break;
    case TUBE_SOLID:
      renderTubeSolid();
      break;
  }
}

void animateTube() {
  if (tubeEffect == TUBE_OFF) return;

  unsigned long now = millis();
  uint16_t interval = map(tubeSpeed, 0, 255, 80, 8);
  if (now - lastAnimMs < interval) return;
  lastAnimMs = now;

  if (tubeEffect == TUBE_CHASE) {
    chaseHead = (chaseHead + 1) % NUM_TUBE_LEDS;
  } else if (tubeEffect == TUBE_GRADIENT_WAVE) {
    tubeAnimOffset = (tubeAnimOffset + map(tubeSpeed, 0, 255, 1, 12)) & 0xFF;
  }

  renderTube();
  showAll();
}

void blackoutAll() {
  fill_solid(modules, NUM_MODULE_PIXELS, CRGB::Black);
  tubeEffect = TUBE_OFF;
  tubeBlackout();
  showAll();
}

void setModuleRgb(int index, uint8_t r, uint8_t g, uint8_t b) {
  if (index < 0 || index >= NUM_MODULES) return;
  moduleR[index] = r;
  moduleG[index] = g;
  moduleB[index] = b;
  applyModuleColor(index);
  showAll();
}

int ccToModuleChannel(byte cc, int *channel) {
  for (int m = 0; m < NUM_MODULES; m++) {
    for (int c = 0; c < 3; c++) {
      if (CC_RGB_MAP[m][c] == cc) {
        *channel = c;
        return m;
      }
    }
  }
  return -1;
}

void onNoteOn(byte channel, byte note, byte velocity) {
  if (MIDI_CHANNEL != 0 && channel != MIDI_CHANNEL) return;
  if (velocity == 0) {
    onNoteOff(channel, note, velocity);
    return;
  }

  int idx = note - MIDI_NOTE_MODULE_1;
  if (idx < 0 || idx >= NUM_MODULES) return;

  applyModuleColorScaled(idx, midiToByte(velocity));
  showAll();
}

void onNoteOff(byte channel, byte note, byte velocity) {
  if (MIDI_CHANNEL != 0 && channel != MIDI_CHANNEL) return;

  int idx = note - MIDI_NOTE_MODULE_1;
  if (idx < 0 || idx >= NUM_MODULES) return;

  fillModulePixels(idx, CRGB::Black);
  showAll();
}

void onControlChange(byte channel, byte cc, byte value) {
  if (MIDI_CHANNEL != 0 && channel != MIDI_CHANNEL) return;

  if (cc == 7) {
    masterBrightness = midiToByte(value);
    FastLED.setBrightness(masterBrightness);
    for (int i = 0; i < NUM_MODULES; i++) applyModuleColor(i);
    renderTube();
    showAll();
    return;
  }

  if (cc == CC_TUBE_EFFECT) {
    tubeEffect = (TubeEffect)map(value, 0, 127, 0, TUBE_SOLID);
    renderTube();
    showAll();
    return;
  }
  if (cc == CC_TUBE_HUE) {
    tubeHue = midiToByte(value);
    renderTube();
    showAll();
    return;
  }
  if (cc == CC_TUBE_SPEED) {
    tubeSpeed = midiToByte(value);
    return;
  }
  if (cc == CC_TUBE_DENSITY) {
    tubeDensity = midiToByte(value);
    renderTube();
    showAll();
    return;
  }
  if (cc == CC_TUBE_SOLID_BRI) {
    tubeSolidBrightness = midiToByte(value);
    if (tubeEffect == TUBE_SOLID) {
      renderTube();
      showAll();
    }
    return;
  }

  int rgbCh;
  int mod = ccToModuleChannel(cc, &rgbCh);
  if (mod >= 0) {
    uint8_t v = midiToByte(value);
    if (rgbCh == 0) moduleR[mod] = v;
    else if (rgbCh == 1) moduleG[mod] = v;
    else moduleB[mod] = v;
    applyModuleColor(mod);
    showAll();
  }
}

void onProgramChange(byte channel, byte program) {
  if (MIDI_CHANNEL != 0 && channel != MIDI_CHANNEL) return;

  switch (program) {
    case 0:
      blackoutAll();
      break;
    case 1:
      for (int i = 0; i < NUM_MODULES; i++) setModuleRgb(i, 255, 180, 80);
      break;
    case 2:
      for (int i = 0; i < NUM_MODULES; i++) setModuleRgb(i, 255, 0, 0);
      break;
    case 3:
      for (int i = 0; i < NUM_MODULES; i++) setModuleRgb(i, 0, 255, 0);
      break;
    case 4:
      for (int i = 0; i < NUM_MODULES; i++) setModuleRgb(i, 0, 0, 255);
      break;
    case 5:
      for (int i = 0; i < NUM_MODULES; i++) setModuleRgb(i, 255, 0, 255);
      break;
    case 6:
      for (int i = 0; i < NUM_MODULES; i++) setModuleRgb(i, 255, 255, 255);
      break;
    // --- Presets tubo ---
    case 7:
      tubeEffect = TUBE_GRADIENT_WAVE;
      tubeHue = 160;
      tubeSpeed = 120;
      tubeDensity = 80;
      renderTube();
      showAll();
      break;
    case 8:
      tubeEffect = TUBE_CHASE;
      tubeHue = 0;
      tubeSpeed = 150;
      tubeDensity = 100;
      renderTube();
      showAll();
      break;
    case 9:
      tubeEffect = TUBE_RAINBOW;
      renderTube();
      showAll();
      break;
    case 10:
      tubeEffect = TUBE_OFF;
      tubeBlackout();
      showAll();
      break;
    default:
      break;
  }
}

void bootTestTube() {
  tubeEffect = TUBE_GRADIENT_WAVE;
  tubeHue = 96;
  tubeSpeed = 200;
  tubeDensity = 70;

  for (int step = 0; step < NUM_TUBE_LEDS + 16; step++) {
    tubeAnimOffset = (tubeAnimOffset + 14) & 0xFF;
    renderTubeGradientWave();
    showAll();
    delay(35);
  }

  tubeEffect = TUBE_OFF;
  tubeBlackout();
  showAll();
}

void setup() {
  FastLED.addLeds<MODULE_LED_TYPE, MODULE_PIN, MODULE_COLOR_ORDER>(modules, NUM_MODULE_PIXELS);
  FastLED.addLeds<TUBE_LED_TYPE, TUBE_PIN, TUBE_COLOR_ORDER>(tube, NUM_TUBE_LEDS);
  FastLED.setBrightness(masterBrightness);
  FastLED.clear(true);

  const CRGB bootColors[] = { CRGB::Red, CRGB::Green, CRGB::Blue, CRGB::White };
  for (int i = 0; i < NUM_MODULES; i++) {
    fillModulePixels(i, bootColors[i]);
    showAll();
    delay(150);
    fillModulePixels(i, CRGB::Black);
  }

  bootTestTube();

#if ENABLE_SERIAL_MIDI
  Serial1.begin(SERIAL_MIDI_BAUD);
#endif

#if ENABLE_USB_MIDI
  if (MIDI_CHANNEL == 0) {
    MIDI.begin(MIDI_CHANNEL_OMNI);
  } else {
    MIDI.begin(MIDI_CHANNEL);
  }
  MIDI.setHandleNoteOn(onNoteOn);
  MIDI.setHandleNoteOff(onNoteOff);
  MIDI.setHandleControlChange(onControlChange);
  MIDI.setHandleProgramChange(onProgramChange);
#endif

#if ENABLE_SERIAL_MIDI
  if (MIDI_CHANNEL == 0) {
    MIDI_Serial.begin(MIDI_CHANNEL_OMNI);
  } else {
    MIDI_Serial.begin(MIDI_CHANNEL);
  }
  MIDI_Serial.setHandleNoteOn(onNoteOn);
  MIDI_Serial.setHandleNoteOff(onNoteOff);
  MIDI_Serial.setHandleControlChange(onControlChange);
  MIDI_Serial.setHandleProgramChange(onProgramChange);
#endif
}

void loop() {
#if ENABLE_USB_MIDI
  MIDI.read();
#endif
#if ENABLE_SERIAL_MIDI
  MIDI_Serial.read();
#endif
  animateTube();
}

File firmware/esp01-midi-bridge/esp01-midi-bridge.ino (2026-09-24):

/*
 * StageMod — ESP-01 bridge MIDI (UDP → UART)
 *
 * PC envia bytes MIDI brutos para UDP :5004
 * ESP repassa para Serial @ 115200 → Pro Micro Serial1
 *
 * Alimentação: 3.3V only. Ver docs/18-WIRELESS-MIDI.md
 */

#include <ESP8266WiFi.h>
#include <WiFiUdp.h>

// --- configure antes do upload ---
const char* WIFI_SSID = "SUA_REDE";
const char* WIFI_PASS = "SUA_SENHA";
const uint16_t UDP_PORT = 5004;

// IP fixo opcional (comente USE_STATIC_IP se usar DHCP)
#define USE_STATIC_IP 0
IPAddress local_IP(192, 168, 1, 200);
IPAddress gateway(192, 168, 1, 1);
IPAddress subnet(255, 255, 255, 0);

WiFiUDP udp;
uint8_t udpBuf[64];

void setup() {
  Serial.begin(115200);
  delay(10);

  WiFi.mode(WIFI_STA);
  WiFi.setSleep(false);

#if USE_STATIC_IP
  WiFi.config(local_IP, gateway, subnet);
#endif

  WiFi.begin(WIFI_SSID, WIFI_PASS);
  while (WiFi.status() != WL_CONNECTED) {
    delay(200);
  }

  udp.begin(UDP_PORT);
}

void loop() {
  int packetSize = udp.parsePacket();
  if (packetSize <= 0) {
    return;
  }

  if (packetSize > (int)sizeof(udpBuf)) {
    packetSize = sizeof(udpBuf);
  }

  int len = udp.read(udpBuf, packetSize);
  if (len > 0) {
    Serial.write(udpBuf, len);
  }
}

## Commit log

2026-09-15 docs: esboço inicial StageMod — iluminação palco ESP32 + MIDI
    - Arquitetura modular RS-485 com barramento 24 V
    - Análise LEDs: 3× mono 3 W vs RGB 10 W integrado
    - Eletrônica MOSFET + drivers CC (referência vídeo ESP+MOSFET)
    - Alimentação centralizada, fusíveis e injeção de energia
    - Integração MIDI/DAW e protocolo RS-485 rascunho
    - BOM, topologia split/daisy-chain e roadmap de protótipo
2026-09-15 docs: resumo rápido de decisões do projeto
2026-09-15 docs: arquitetura v2 — cabeça única, cabo StageMod, módulo dual 2×10W
    - Um único ESP32-S3 na Cabeça (MIDI → RS-485)
    - Cabo StageMod: 24V + GND + D+/D− + shield (GX16-5)
    - Módulos simples: ATtiny + 2× driver 10W (padrão WW + vermelho)
    - Config futura via modules.json (WW×2, verde+vermelho, etc.)
    - BOM, alimentação e roadmap atualizados
2026-09-15 docs: lente óptica 20 mm por LED (90° wash)
    - Novo doc 12-LENTE-20MM.md: montagem, ângulos, térmica, BOM
    - Módulo Dual: 2 lentes + holders, centros 28-32 mm
    - BOM e roadmap atualizados
2026-09-15 docs: referência lente 20mm na visão geral
2026-09-15 docs: lente 20 mm fixada em 90° em todo o projeto
    Remove alternativas 60°/spot; BOM e estoque só 90°
2026-09-15 docs: cablagem barata — P4 energia + RJ45/Cat5e dados
    Substitui cabo único GX16-5 por dois chicotes comuns (~US--,90/salto).
    Novo 09-CABLAGEM.md; BOM e arquitetura atualizados.
2026-09-15 docs: proteção anti-reverso P4 com P-MOS AO4407
    - Esquema em 03-ELETRONICA, cablagem, módulo, BOM e roadmap
    - Alternativa Schottky SS34 documentada para protótipo
2026-09-15 docs: AO4407 na lista de compra do protótipo
2026-09-15 docs: anti-reverso P-MOS na saída P4 da Cabeça (fonte única)
    - IRF9540N + polyfuse 10A + TVS no barramento de saída
    - Módulos: pass-through sem anti-reverso (proteção centralizada)
    - BOM, cablagem e alimentação atualizados
2026-09-15 feat: protótipo Pro Micro + 4 módulos WS2812B (MIDI USB)
    - Firmware promicro-4mod.ino (FastLED + MIDI Library)
    - Docs de ligação 5V, cadeia data, mapa MIDI C3-F3
    - README e roadmap atualizados para fase v0
2026-09-15 docs: README e roadmap apontam para protótipo Pro Micro
2026-09-15 docs: reestruturação completa para StageMod v0
    - README e docs 00-08 alinhados com Pro Micro + 4× WS2812B RGB
    - Cablagem v0 unificada em 07-CABLAGEM.md
    - Specs v1 (24V, 10W, P4, lentes) movidas para docs/v1/
    - Roadmap, BOM, MIDI e DECISAO-RESUMO atualizados
2026-09-15 feat(v0): tubo flexível WS2812B com gradiente e chase (pin D5)
    - Efeitos: gradient wave, chase, rainbow, solid
    - MIDI CC 15-19 e PC 7-10 para tubo
    - Doc 14-TUBO-FLEX.md; arquitetura e alimentação 3A atualizados
    [promicro-4mod.ino]
2026-09-15 Configurar firmware e docs para tubo neon 4m (200 LEDs)
2026-09-15 Atualizar specs do tubo D15-Woven Magic (WS2811, 50 LED/m, 4m)
2026-09-15 Ajustar dimensionamento fonte para tubo D15 (3,1 W/m)
2026-09-15 Remover fita WS2812B opcional — tubo neon já inclui LEDs
2026-09-24 Documentar cablagem XLR 3 pinos para tubo e módulos WS2812B
2026-09-24 Medusa: entrada AC IEC C14 e SMPS 5V interna
2026-09-29 Padronizar 470Ω e capacitor em cada módulo WS2812B
2026-09-29 Incluir ZS-040 como componente oficial (doc 19, BOM, arquitetura)
2026-09-29 Hardware real: 4×8 LEDs módulos, tubo 200; inventário doc 20
2026-09-29 Lista de compras dos itens restantes (doc 21)
2026-09-29 docs: corrigir RX/TX ZS-040 no manual; README aponta para montagem
2026-09-29 feat(cad): modelo 3D módulo spot v0 (OpenSCAD + STL)
    [spot_body.stl, spot_bottom_plate.stl, spot_diffuser.stl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]
2026-09-29 docs: imagem de referência no guia 3D do spot
2026-09-30 docs: manual de montagem na ordem fonte → Pro Micro → cabos → teste → firmware
2026-09-30 docs: passo a passo ligar fonte 5V no Pro Micro (VCC/GND, não RAW)
2026-09-30 docs: guia detalhado montagem módulos WS2812B (8 LEDs + XLR)
2026-10-03 Publish the audio-reactive tube control page on GitHub Pages.
